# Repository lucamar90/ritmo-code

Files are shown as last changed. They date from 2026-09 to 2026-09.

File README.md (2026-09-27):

<div align="center">

Clawd

# Ritmo Code

**I limiti d'uso di Claude Code, in tempo reale su uno schermo touch da 3,5".**<br>
Senza computer acceso, senza app, senza cloud.

**Italiano** · [English](README.en.md)






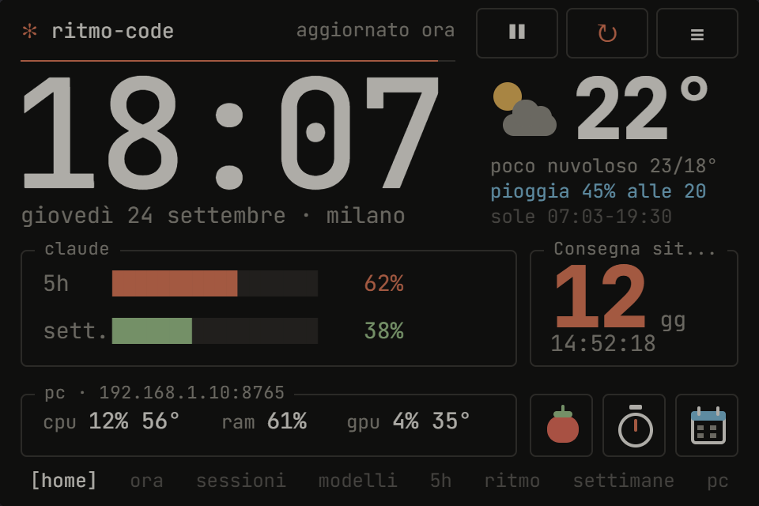
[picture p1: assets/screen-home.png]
Ritmo Code: home con ora, meteo, riepilogo Claude e PC


</div>

Ritmo Code è un piccolo schermo da scrivania che mostra quanto hai consumato delle finestre
di **5 ore** e **settimanale** del tuo abbonamento Claude, quando si azzerano, se il ritmo della
settimana è sostenibile e se i modelli rispondono. Il dispositivo interroga direttamente la API
di Anthropic via Wi-Fi e legge i dati dagli header della risposta.

Sulla stessa scrivania fa anche da cruscotto: ora e meteo, e con l'app
[**Ritmo Code PC Monitor**](#ritmo-code-pc-monitor) le statistiche complete del tuo PC.

L'interfaccia è in stile terminale di Claude Code, in **italiano** o inglese, con navigazione
100% touch (scorri ← → tra le pagine, nessun tasto fisico).

---

## Schermate

| | |
|---|---|
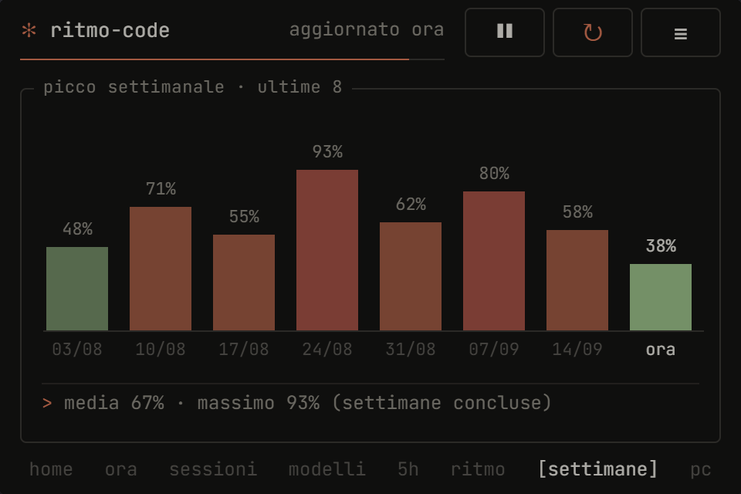
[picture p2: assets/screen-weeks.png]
Settimane
| Home **Home** — ora, data, meteo (Open-Meteo), riepilogo di 5h e settimana, stato dei modelli e riga del PC collegato. Ci torna da sola dopo qualche minuto senza tocchi. |  **Settimane** — picco raggiunto in ciascuna delle ultime 8 settimane, con media e massimo. |
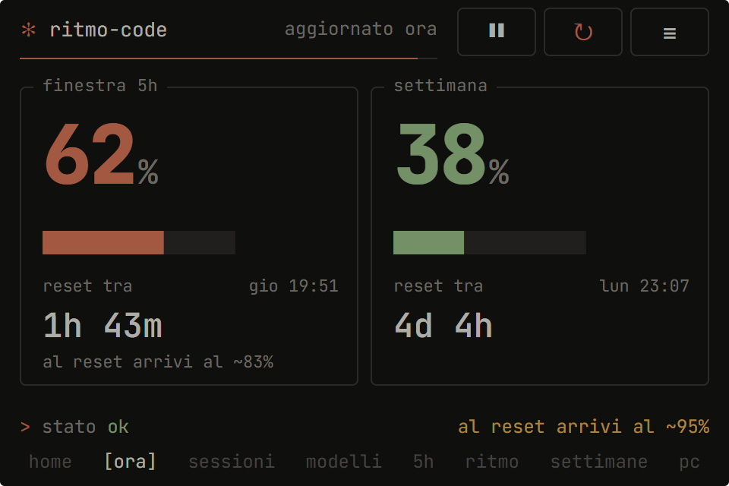
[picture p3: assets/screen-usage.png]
Ora
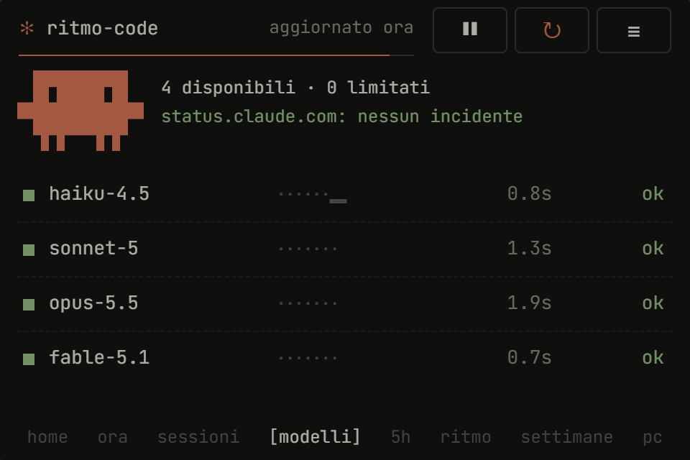
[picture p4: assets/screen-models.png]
Modelli
|  **Ora** — percentuale e barra a blocchi di 5h e settimana, conto alla rovescia e orario del reset, stato complessivo e **ritmo settimanale** (con la tacca "dove dovresti essere"). Sotto il conto alla rovescia della 5h, la **previsione**: "a questo ritmo: fine 16:40" oppure "al reset arrivi al ~70%". |  **Modelli** — Clawd reagisce allo stato; per Haiku, Sonnet, Opus e Fable una sonda reale con esito e latenza, più gli incidenti da status.claude.com. |
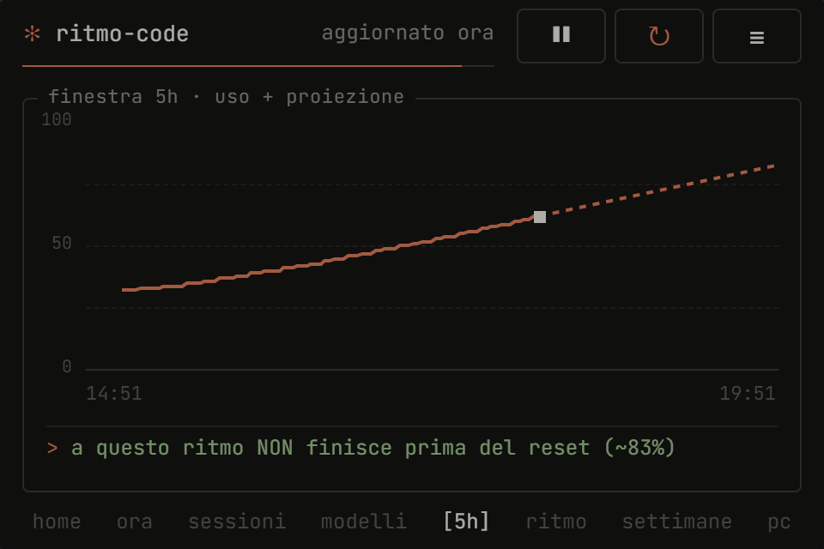
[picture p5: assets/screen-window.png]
Finestra 5h
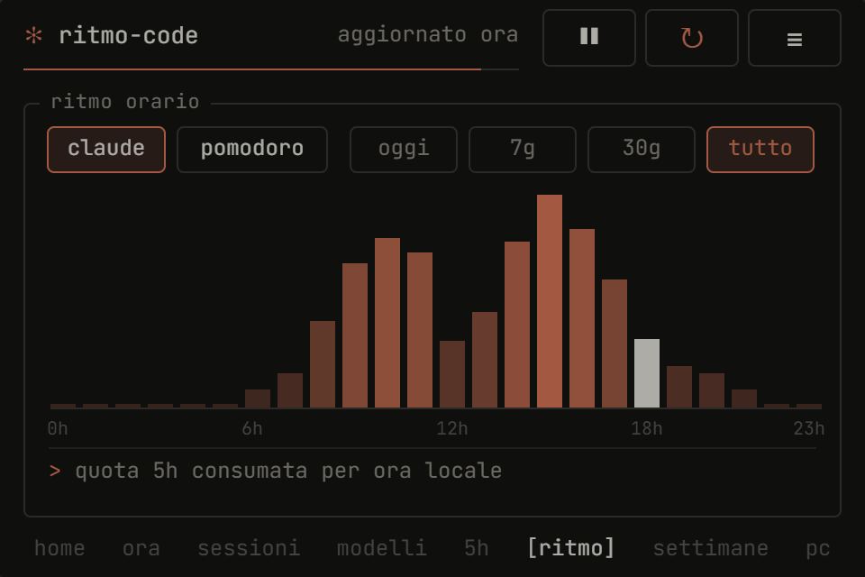
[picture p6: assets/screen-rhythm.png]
Ritmo
|  **Finestra 5h** — uso della finestra corrente e proiezione tratteggiata: ti dice se, a questo ritmo, finisci la quota prima del reset. |  **Ritmo** — quota consumata per ora del giorno, con filtro **oggi · 7g · 30g · tutto** (storico per giorno salvato sul dispositivo). La riga in basso alterna i **progetti** del periodo: toccala per il pannello completo. |
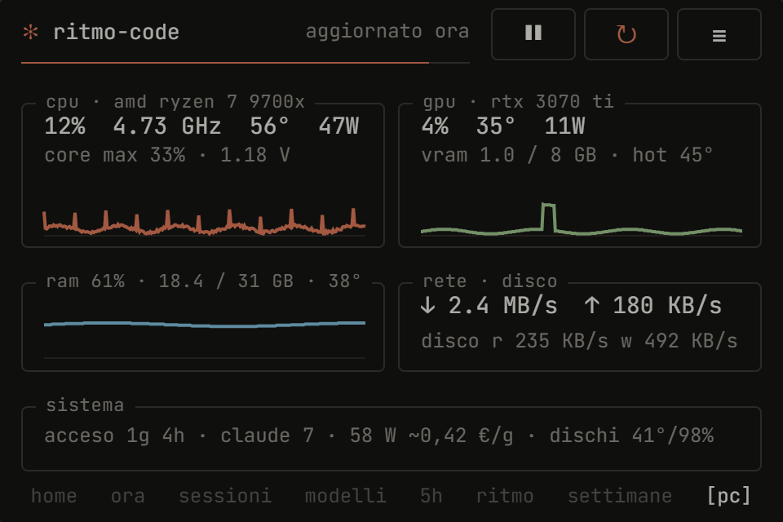
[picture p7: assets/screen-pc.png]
PC
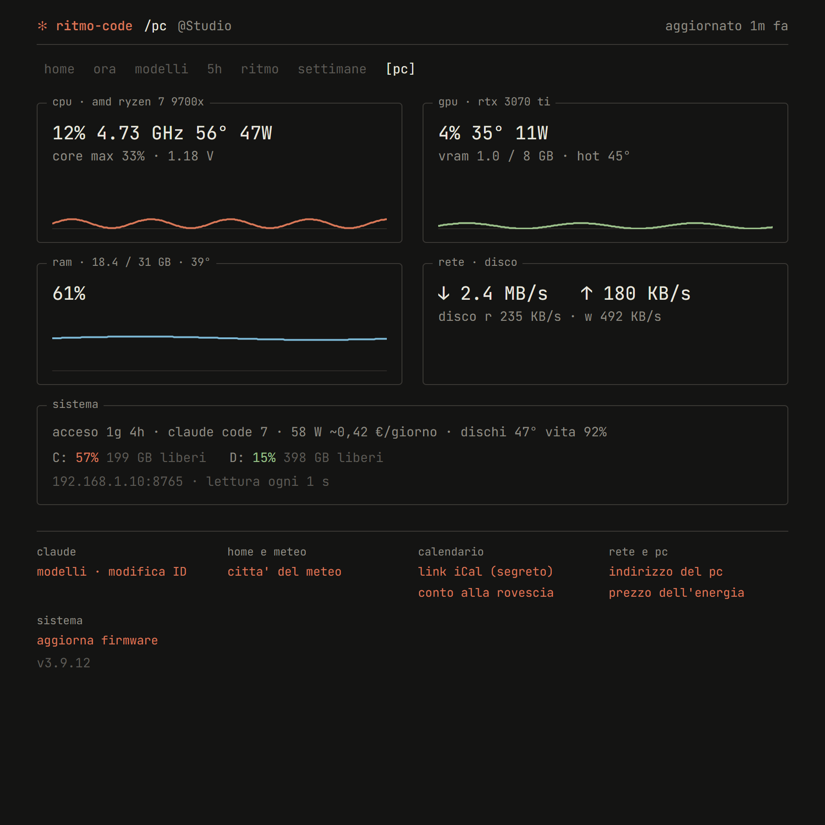
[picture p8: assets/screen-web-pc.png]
Pannello web, pagina pc
|  **PC** — CPU (carico, GHz, temperatura, watt, core più carico), GPU (VRAM e hot spot), RAM con temperatura dei moduli, rete, disco, grafici che avanzano a ogni lettura (4 minuti a 1 s), uptime, sessioni di Claude Code, consumo e costo al giorno, temperatura e vita residua dei dischi. |  **Pannello web · pc** — le stesse pagine del dispositivo nel browser, con i dischi uno per uno. |
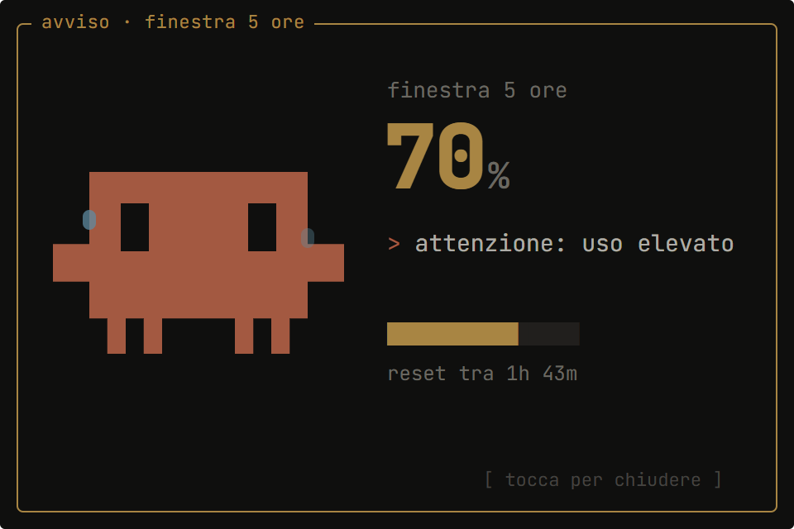
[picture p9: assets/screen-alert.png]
Avviso di soglia
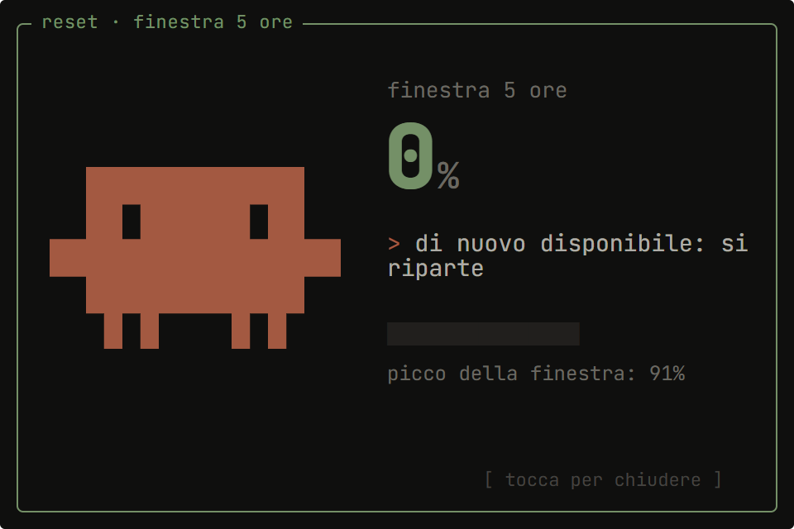
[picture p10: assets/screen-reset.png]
Avviso di reset
|  **Avvisi di soglia** — a 25, 50, 70 e 100% un'animazione a schermo intero con Clawd che reagisce al livello. |  **Avviso di reset** — quando una finestra che aveva superato l'80% torna disponibile. |
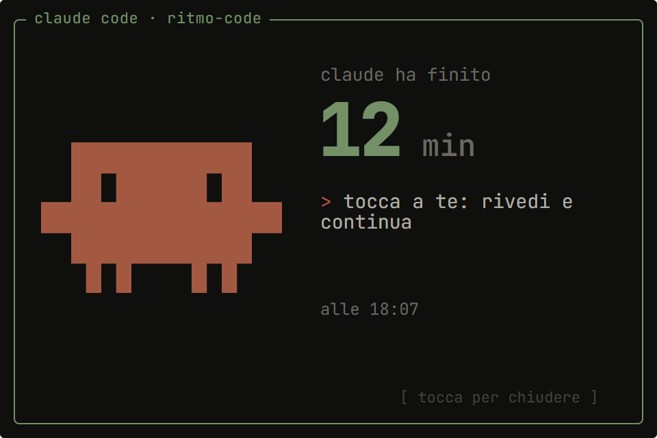
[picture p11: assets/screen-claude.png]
Claude ha finito
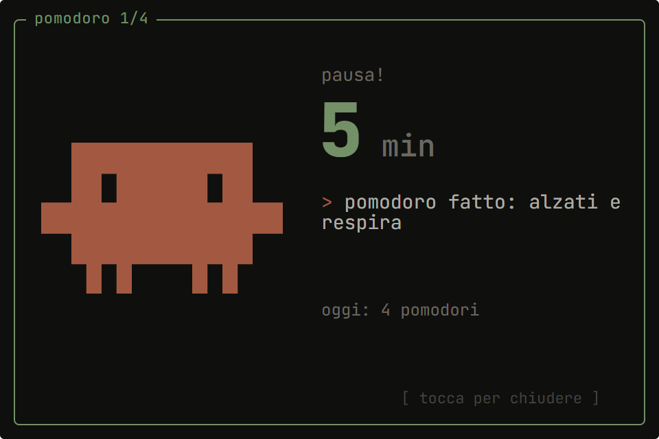
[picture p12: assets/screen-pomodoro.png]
Pomodoro
|  **Claude Code** — con gli hook installati dal PC Monitor, Clawd ti avvisa quando Claude ha finito (e dopo quanto) o aspetta un permesso. Resta finché non lo tocchi o riscrivi a Claude. |  **Timer e pomodoro** — tocca l'ora o il pomodoro nella home: pomodoro 25/5, 50/10 o 15/3, oppure timer da 5 a 30 minuti. Conto alla rovescia sotto l'ora, avviso a fine fase, pomodori di oggi. |
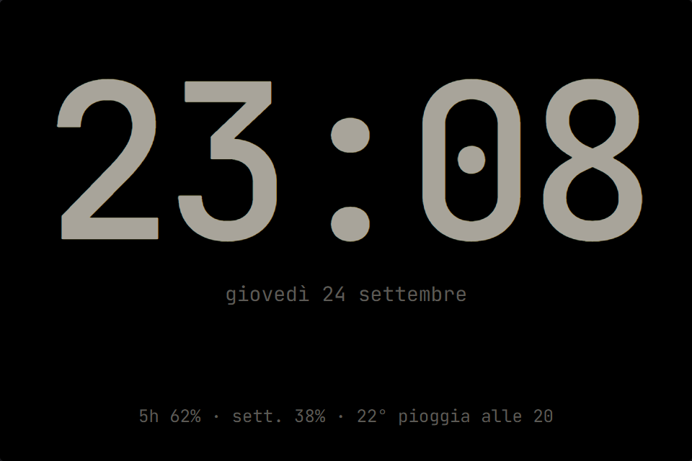
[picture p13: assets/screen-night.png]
Orologio notturno
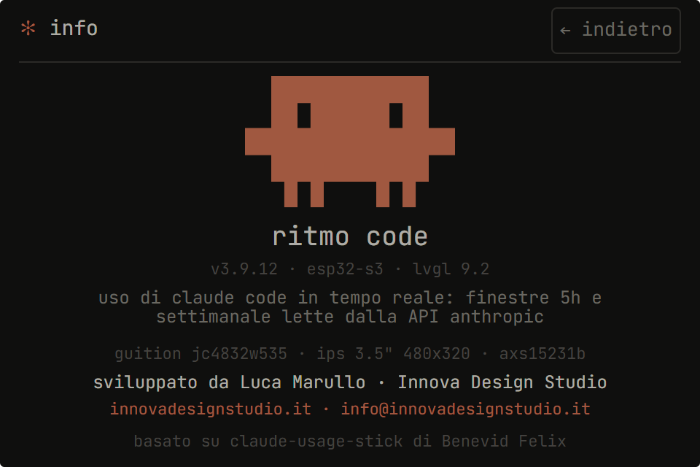
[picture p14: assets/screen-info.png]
Info
|  **Orologio notturno** — di notte, dopo 30 secondi senza tocchi, l'ora a tutto schermo in grigio caldo con data, uso di 5h e settimana e pioggia in arrivo. Luminosità tenue o molto tenue; in alternativa lo schermo si spegne. |  **Info** — versione del firmware, hardware e crediti. |
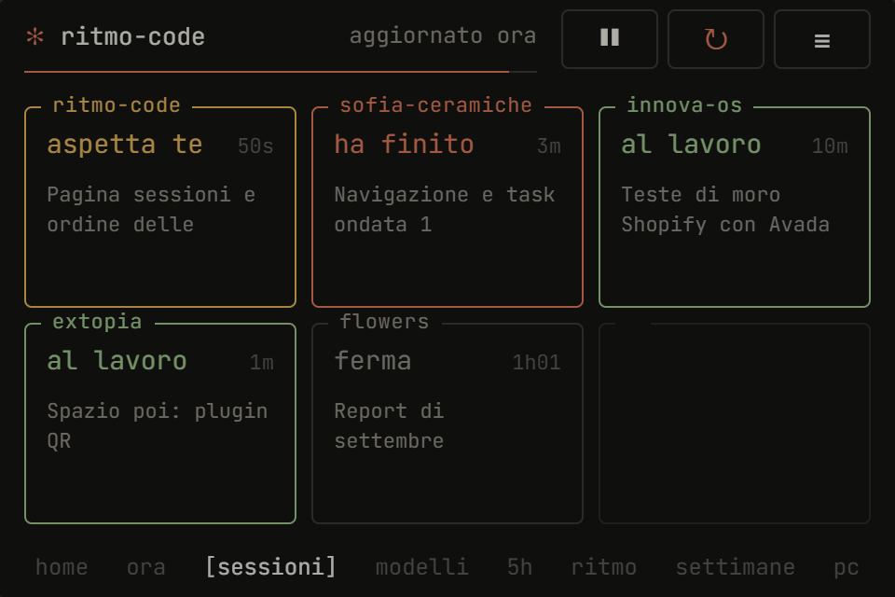
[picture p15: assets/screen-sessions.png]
Sessioni
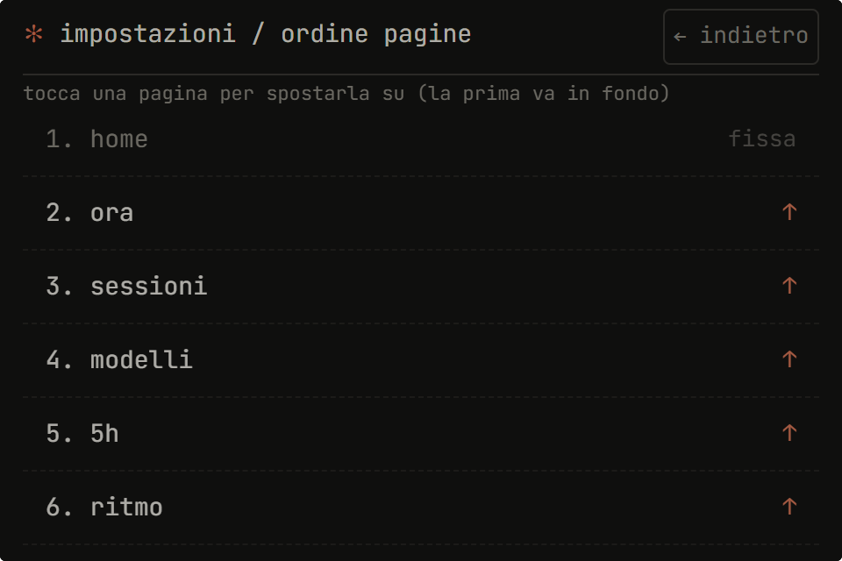
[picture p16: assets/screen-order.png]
Ordine delle pagine
|  **Sessioni** — le sessioni di Claude Code aperte sul PC (fino a 6): progetto, stato col suo colore (**aspetta te**, **ha finito**, **al lavoro**, **ferma**), da quanto e titolo della scheda. Un tocco porta la sessione in primo piano sul PC; se sei su questa pagina, chi finisce o ti aspetta lampeggia invece di aprire l'avviso a schermo intero. |  **Ordine delle pagine** — in *Impostazioni → schermo → ordine pagine* scegli la sequenza delle pagine (la home resta la prima). Predefinito: home · ora · sessioni · modelli · 5h · ritmo · settimane · pc. |
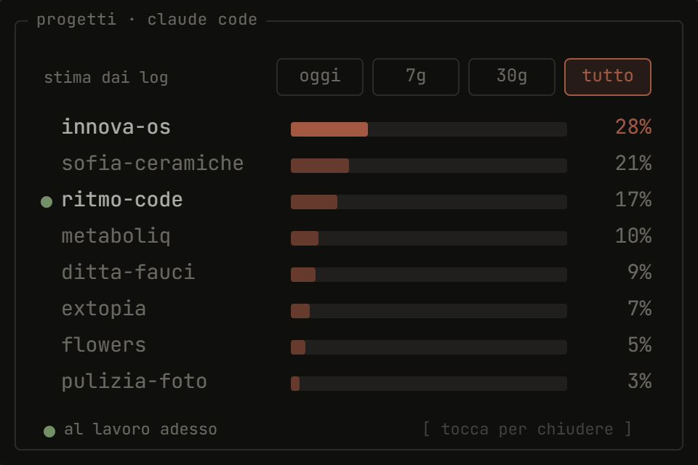
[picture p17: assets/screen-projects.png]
Progetti
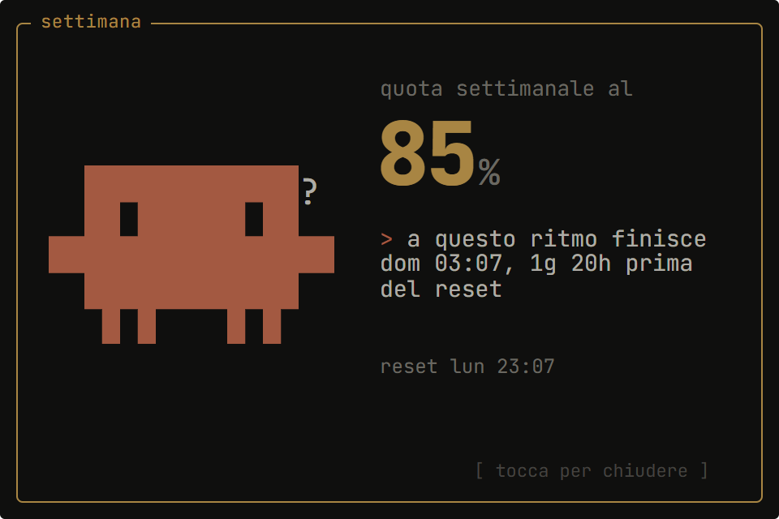
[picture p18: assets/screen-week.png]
Avviso settimana
|  **Progetti** — quanto pesa ogni progetto su Claude Code nel periodo scelto (fino a 8), con barra e percentuale; il pallino verde segna quelli con una sessione al lavoro adesso. Dati dal PC Monitor 1.9. |  **Avviso settimana** — se la settimana supera il 70, 85 o 95% e a questo ritmo finirebbe almeno 12 ore prima del reset, Clawd ti avvisa (una volta a settimana). |
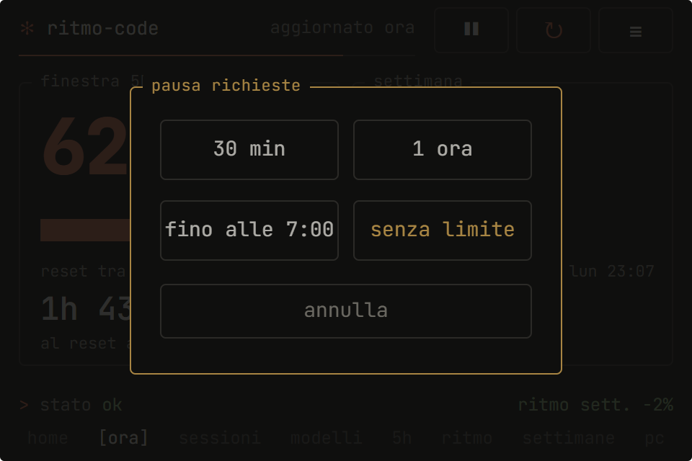
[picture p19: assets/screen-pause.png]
Pausa a tempo
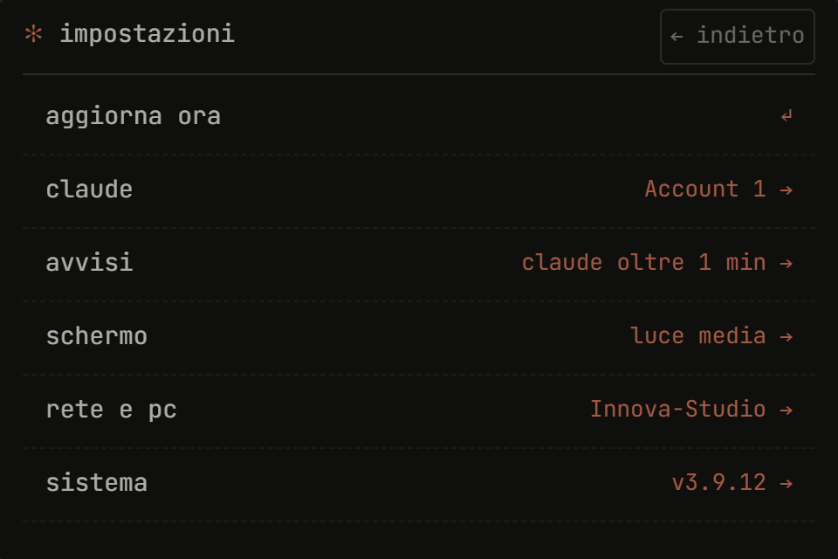
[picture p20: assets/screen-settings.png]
Impostazioni
|  **Pausa richieste** — il tasto ❚❚ in testata ferma le richieste; tenuto premuto offre 30 min, 1 ora, fino alle 7:00 o senza limite. |  **Impostazioni** — in cinque gruppi: **claude** (intervallo, account, modelli, token), **avvisi** (Claude Code, calendario, suoni sul pc, settimana, reset, pausa), **schermo** (luminosità e luminosità automatica, notte e orologio notturno, attenuazione, home, slideshow, tendina, ordine delle pagine), **rete e pc** (Wi-Fi, indirizzo, intervallo pc, ricerca della scheda per le sessioni) e **sistema** (lingua, fuso, aggiornamento firmware, spazio libero e RAM, info; *cancella tutto* chiede due tocchi e il PIN). |

> Doppio tocco su **✻ ritmo-code** in alto: riapre l'ultimo avviso (Claude, timer, pomodoro o soglia).

Le immagini arrivano dal [simulatore](#simulatore) e si rigenerano con `node tools/capture_screens.js`.

### Pannello web

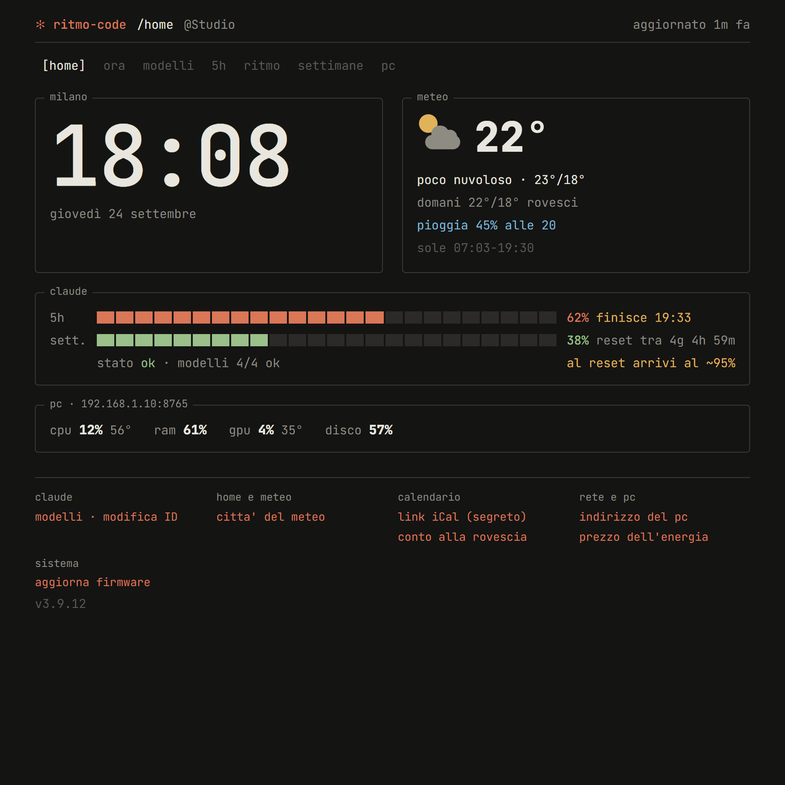
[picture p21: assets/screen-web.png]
Pannello web di Ritmo Code


Da qualsiasi browser sulla stessa rete apri **`http://<ip-del-dispositivo>/`**: l'IP è in
*Impostazioni → rete locale* (su Mac e iPhone funziona anche `http://ritmo-code.local/`).

- Meteo e PC collegato in un riquadro in alto.
- Finestra 5h e settimana con conto alla rovescia, stato, ritmo e previsione (della 5h e della settimana).
- Le schede del dispositivo: **home · ora · modelli · 5h · ritmo · settimane · pc** (la pagina sessioni c'è solo sul dispositivo).
- **Andamento** dello storico con filtro **6h · 24h · tutto**.
- **Ritmo orario** con filtro **oggi · 7g · 30g · tutto** e, sotto, i **progetti** del periodo con il pallino di quelli al lavoro.
- Modelli sondati: ID, esito, latenza, ultimo controllo.
- **Picco settimanale** delle ultime 8 settimane.
- Collegamenti per **modificare gli ID dei modelli**, impostare **città, PC e prezzo dell'energia** (`/home`) e **aggiornare il firmware**.

Si aggiorna da solo ogni 30 secondi leggendo solo la memoria del dispositivo (`/api/status`):
nessuna richiesta in più ad Anthropic, e il token non viene mai esposto.

<br clear="right">

---

## Funzioni

- **Finestre 5h e settimanale** con reset, proiezione ed esito complessivo (`ok` · `attenzione` · `bloccato`).
- **Ritmo settimanale**: percentuale usata meno percentuale di settimana trascorsa. Verde se sei sotto ritmo, ambra fino a +15%, rosso oltre. Alternato alla **previsione**: "al reset arrivi al ~70%" oppure "a questo ritmo finisce gio 14:00".
- **Previsione della 5h** col ritmo degli ultimi 45 minuti, nella pagina ora ("a questo ritmo: fine 16:40") e in home, dove "finisce 16:40" prende il posto dell'orario di reset quando la quota finisce prima.
- **Avviso settimana**: sopra il 70, 85 o 95% (*Impostazioni → avvisi → avviso settimana*, predefinito 85%), se a questo ritmo la quota settimanale finisce almeno 12 ore prima del reset, un avviso a schermo intero dice quando finisce e con quanto anticipo. Una volta a settimana.
- **Progetti di Claude Code**: il PC Monitor legge i log delle sessioni (`~/.claude/projects`) e stima quanto pesa ogni progetto oggi, in 7 giorni, in 30 giorni e da sempre (token pesati come i prezzi e per famiglia del modello). Il progetto è il repository git della cartella di lavoro, con il nome del remote; nelle cartelle `clienti\` e `interno\` conta la sottocartella. Nella pagina ritmo e nel pannello web.
- **Storico settimanale**: picco di ogni settimana, salvato sul dispositivo per account.
- **Avvisi** di soglia (25/50/70/100%) e di **reset** (disattivabile).
- **Timer e pomodoro**: tocca l'ora o la riga con il pomodoro nella home. Tre impostazioni pronte, **25/5**, **50/10** e **15/3** (focus/pausa in minuti, pausa lunga dopo il quarto), oppure timer da 5, 10, 15 o 30 minuti. Il conto alla rovescia scorre sotto l'ora e nella testata, a fine fase Clawd lo annuncia a schermo intero (anche di notte) e i pomodori di oggi restano contati. Si comanda anche dal PC (menu dell'icona) e, con *Impostazioni → avvisi → claude durante il focus → alla pausa*, gli avvisi di Claude aspettano la fine del focus.
- **Calendario**: incolla il link segreto iCal di Google Calendar (o Outlook) nel pannello web, pagina `/home`. Il PC Monitor scarica gli eventi ogni 5 minuti (anche quelli ricorrenti); sotto l'ora compare "tra 12 min: call cliente" o "in corso: … fino 16:00", e 5, 10 o 15 minuti prima arriva un avviso a schermo intero con suono sul PC (*Impostazioni → avvisi → avviso calendario*). Il link lo legge solo il PC collegato.
- **Sessioni di Claude Code**: una pagina con le sessioni aperte sul PC e il loro stato. Un tocco apre la sessione: il PC Monitor risale dal processo di Claude alla finestra del terminale e la porta davanti; in **Warp** scorre anche le schede (Ctrl+PgGiù) finché il titolo corrisponde (*Impostazioni → rete e pc → sessioni: cerca la scheda*). Sotto il riquadro compare l'esito: *aperta*, *cambia scheda* o *finestra non trovata*.
- **Avvisi di Claude Code**: Clawd ti dice quando Claude ha finito un lavoro (con la durata) o aspetta un permesso, tramite gli hook e l'app [PC Monitor](#ritmo-code-pc-monitor). Mentre Claude lavora la ✻ in testata gira come in Claude Code e il riquadro della home dice quante sessioni sono **al lavoro**.
- **Modelli**: una sonda per ciclo a rotazione. Gli **ID sono modificabili** dal dispositivo o dal browser: se Anthropic rinomina un modello non serve ricompilare.
- **Modalità notte** in una fascia oraria (22, 23 o 00 → 07): **orologio a tutto schermo** con luminosità tenue o molto tenue, oppure schermo spento, e di predefinito **aggiornamenti in pausa**. Il primo tocco riaccende soltanto, senza premere nulla. **Attenuazione** dopo 1, 5 o 10 minuti senza tocchi.
- **Luminosità automatica**: piena di giorno e bassa la sera, dal tramonto all'alba (orari presi dal meteo) oppure 20→07 o 21→07. Un tocco sul livello vale fino al passaggio successivo.
- **Pausa richieste** dal tasto in testata, senza limite o a tempo; riparte da sola.
- **Tendina** (trascina giù dalla testata): segnale Wi-Fi, indirizzo e PC collegato (tocca per la pagina rete), **quattro tasti a scelta** fra richieste, timer, luce, suoni sul PC, aggiorna, calendario e meteo (*Impostazioni → schermo → tendina*), il **riepilogo di oggi** (pomodori, richieste a Claude e tempo di lavoro, 5 ore), il **prossimo evento** (tocca per aprire il calendario su quel giorno) e gli ultimi tre avvisi.
- **Promemoria pausa**: dopo 45, 60 o 90 minuti di PC in uso senza staccare (mouse e tastiera, letti dal PC Monitor) Clawd ti ricorda di alzarti; si ripete ogni mezz'ora e si azzera dopo 5 minuti lontano dal PC (*Impostazioni → avvisi*).
- **Media**: quando sul PC parte la musica o un video (Spotify, browser, lettori) si apre la pagina media: copertina, titolo, artista, barra di avanzamento (tocca per spostarti), indietro / play-pausa / avanti e volume del PC. Si apre anche dalla tendina; l'apertura automatica si spegne in *Impostazioni → schermo*. Serve il PC Monitor 1.8.
- **Conto alla rovescia**: fino a tre date con nome ("consegna sito tra 12 giorni"), da creare sul dispositivo (tendina → conto) o dal pannello web, pagina `/home`. All'arrivo Clawd avvisa con un suono sul PC.
- **Claude oggi**: richieste finite, tempo totale di lavoro e la più lunga, nella tendina e nella pagina ritmo (scheda claude, periodo *oggi*).
- **Home e meteo**: ora, data e previsioni per la città scelta (Open-Meteo, gratuito e senza chiave), aggiornate ogni 30 minuti. Tocca il meteo per le **previsioni dei 7 giorni**.
- **Statistiche del PC** tramite l'app [Ritmo Code PC Monitor](#ritmo-code-pc-monitor), lette ogni 1, 3, 5 secondi o 1 minuto.
- **Fino a 4 account**, cifrati con lo stesso PIN: viene interrogato solo quello attivo.
- **Reti Wi-Fi salvate**: fino a 3, con rete preferita e "dimentica"; il segnale in dBm è nelle impostazioni.
- **Aggiornamento firmware con un tocco**: il dispositivo controlla da solo l'ultima release su GitHub (dopo l'avvio e una volta al giorno), la testata mostra *nuova v…* e in *Impostazioni → sistema → aggiornamenti* si installa con un tocco. Resta anche l'aggiornamento dal browser, protetto da un codice mostrato sullo schermo; in entrambi i casi c'è il **ritorno automatico** alla versione precedente se il nuovo firmware non parte.
- **Layout in sezione aurea**: margini, colonne, altezze dei riquadri e spazi seguono φ e la scala di Fibonacci (5 · 8 · 13 · 21 · 34 · 55 · 89), con padding simmetrici in ogni pagina.
- **Intervallo** di aggiornamento da 30 s a 30 min, **slideshow** automatico, **luminosità**, **fuso orario** (Roma con ora legale automatica, o GMT±N).

---

## Ritmo Code PC Monitor

Pagina pc

App per Windows nella cartella [`ritmo-code-pc-monitor/`](ritmo-code-pc-monitor/) che invia al
dispositivo le statistiche del computer: CPU, GPU, RAM, rete, dischi, uptime, sessioni di Claude
Code aperte e, tramite [LibreHardwareMonitor](https://github.com/LibreHardwareMonitor/LibreHardwareMonitor)
incluso nel pacchetto, temperature, consumi, ventole e salute dei dischi. Dalla 1.9 legge anche i
log di Claude Code sul PC per la ripartizione per **progetto** (al dispositivo arrivano solo nomi e
percentuali).

I dati restano sulla rete di casa: il dispositivo legge `http://<ip-del-pc>:8765/data.json`, che
non contiene nomi di file, processi o finestre. I sensori disponibili dipendono dall'hardware:
temperature, consumi e dischi compaiono solo se LibreHardwareMonitor riesce a leggerli su quel PC.

<br clear="right">

### Installazione su Windows

**Serve:** Windows 10 o 11, un account amministratore, il PC e il dispositivo sulla **stessa rete**
(il dispositivo usa solo il Wi-Fi a **2,4 GHz**; il PC può stare anche via cavo o sul 5 GHz dello
stesso router). Per creare il pacchetto serve anche [Python 3.8+](https://www.python.org/downloads/).

**1. Prendi il pacchetto**

Il modo più rapido: scarica **`RitmoCodePcMonitor-…-windows.zip`** dall'[ultima release](https://github.com/lucamar90/ritmo-code/releases/latest)
e scompattalo; contiene già tutto, non serve Python. Per crearlo da sorgente invece (su qualsiasi PC Windows):

```bat
cd ritmo-code-pc-monitor
pip install pyinstaller
build_exe.bat
```

`build_exe.bat` crea due eseguibili e, se manca, scarica LibreHardwareMonitor 0.9.6. Alla fine la
cartella `dist\` contiene tutto quello che serve:

```
dist\
  RitmoCodePcMonitor-nascosto.exe   senza finestra, avviato con Windows (icona vicino all'orologio)
  RitmoCodePcMonitor.exe            con finestra, per le verifiche
  LibreHardwareMonitor\             sensori, web server solo su 127.0.0.1:8085
  installa.bat · disinstalla.bat · LEGGIMI.txt
```

**2. Installa** sul PC da monitorare

1. Copia la cartella (`dist\` o quella scompattata dallo zip) in un posto fisso, per esempio `C:\RitmoCodePcMonitor` (gli avvii automatici
   puntano lì: non spostarla dopo).
2. Doppio clic su **`installa.bat`** e conferma i permessi di amministratore. Lo script:
   - crea la regola del firewall **"Ritmo Code PC Monitor"**: porta TCP 8765 aperta **solo alla rete locale**;
   - registra LibreHardwareMonitor come attività all'accesso con privilegi elevati (servono per le temperature);
   - mette l'app in *Esecuzione automatica* e la avvia;
   - apre la pagina di collegamento.
3. Se Windows SmartScreen avvisa che l'app non è riconosciuta (gli eseguibili non sono firmati),
   scegli **Ulteriori informazioni → Esegui comunque**.

**3. Collega il PC al dispositivo**

1. Il dispositivo deve essere acceso, sbloccato con il PIN e sulla stessa rete.
2. La pagina **`http://127.0.0.1:8765/`** (si apre da sola, oppure doppio clic sull'icona) cerca il
   dispositivo sulla rete locale. Se non lo trova, controlla la rete e premi **Cerca di nuovo**;
   in alternativa imposta l'indirizzo del PC dal pannello web del dispositivo (vedi sotto).
3. Inserisci il **PIN** del dispositivo e premi **Collega questo PC**. L'app comunica al dispositivo
   il suo indirizzo; il PIN serve solo per questa operazione e non viene salvato.
4. Dopo pochi secondi la pagina **pc** del dispositivo si riempie. La frequenza di lettura si sceglie
   sul dispositivo in *Impostazioni → intervallo pc* (1 s, 3 s, 5 s, 1 min).

In alternativa l'indirizzo del PC (`192.168.x.x:8765`) si imposta anche dal pannello web del
dispositivo, pagina `/home`.

**4. Icona nell'area di notifica**

L'app resta vicino all'orologio di Windows con l'icona di Clawd:

- **passandoci sopra** mostra CPU, GPU, RAM e se il dispositivo sta leggendo i dati;
- **doppio clic** apre la pagina di stato e collegamento;
- **clic destro** apre il pannello del dispositivo o chiude l'app (**Esci**);
- **clic destro → Timer e pomodoro** avvia sul dispositivo un pomodoro (25/5, 50/10, 15/3) o un timer, lo ferma o salta la fase; in cima mostra il timer in corso.

**5. Avvisi di Claude Code**

Avviso: Claude ha finito

Il dispositivo può avvisarti quando Claude Code **ha finito** un lavoro o **aspetta un tuo permesso**,
anche se stai guardando un'altra finestra o ti sei alzato dalla scrivania.

1. Nella pagina **`http://127.0.0.1:8765/`**, riquadro *avvisi di claude code*, premi **Attiva gli avvisi**.
   L'app aggiunge cinque [hook](https://docs.claude.com/en/docs/claude-code/hooks) a
   `~/.claude/settings.json` (`UserPromptSubmit`, `Stop`, `Notification` e, dalla 1.9, `SessionStart` e
   `SessionEnd` per la pagina sessioni) senza toccare il resto del file; la prima volta ne salva una
   copia in `settings.json.ritmo-bak`. Se c'erano già gli hook della 1.8, la 1.9 aggiunge da sola i due nuovi.
2. Apri una nuova sessione di Claude Code: gli hook valgono per le sessioni avviate dopo.

Gli hook chiamano solo `http://127.0.0.1:8765` e l'app inoltra l'avviso al dispositivo, che lo accetta
solo dal PC collegato. Arrivano il nome della cartella del progetto e, per la pagina sessioni, il
**titolo** della sessione (il riassunto di poche parole che Claude Code dà alla scheda); nient'altro del
contenuto della sessione.
A schermo l'avviso si chiude da solo dopo 5, 10 o 30 secondi (*Impostazioni → chiudi avviso claude*, 30 s
predefinito) oppure resta finché non lo tocchi o scrivi di nuovo a Claude (*mai*); di
notte, con lo schermo spento o l'orologio notturno, non compare. In *Impostazioni → avvisi claude code*
scegli quando mostrarlo: **sempre**, solo per lavori **oltre 1 min** (predefinito) o **oltre 5 min**,
oppure **spento**. Le richieste di permesso compaiono sempre, tranne con *spento*.

Per toglierli: **Disattiva** nella stessa pagina.

**6. Suoni e notifiche sul PC**

Quando il dispositivo mostra un avviso (fine del timer, pausa e ripresa del pomodoro, Claude ha finito o
aspetta, soglie di utilizzo e reset) lo manda anche al PC collegato, che suona (un suono diverso per ogni
tipo) e mostra una notifica di Windows. Nella pagina `http://127.0.0.1:8765/`, riquadro *suoni e
notifiche*, scegli suono e notifica e il tipo di suono: **suoni di Windows** (predefiniti, seguono il volume
dei *Suoni di sistema* e si sentono anche in desktop remoto) o **melodie Ritmo Code** (con volume proprio);
**Prova** fa sentire com'è. Sul dispositivo si accende e
spegne da *Impostazioni → suoni sul pc*; di notte resta muto. Il PC accetta gli avvisi solo dal
dispositivo collegato.

<br clear="right">

**Problemi comuni**

| Sintomo | Cosa fare |
|---|---|
| Sul dispositivo: *pc spento o Ritmo Code PC Monitor non attivo* | Controlla che l'icona sia vicino all'orologio. Apri `http://<ip-del-pc>:8765/data.json` da un altro dispositivo: se non risponde, la regola del firewall manca (rilancia `installa.bat`) o il router isola i client Wi-Fi. |
| Il dispositivo non trova il PC dopo un riavvio del router | L'IP del PC è cambiato: rifai **Collega questo PC**, oppure riserva l'indirizzo del PC nel router (DHCP statico). |
| Il PC non trova il dispositivo | Il dispositivo è su un'altra rete (per esempio l'ospite o un altro SSID): in *Impostazioni → reti wifi* dimentica quella sbagliata. |
| Temperature, watt o dischi vuoti | LibreHardwareMonitor deve girare come amministratore: esci e rientra in Windows, o rilancia `installa.bat`. Alcuni chip della scheda madre non sono supportati. |
| *Porta 8765 già in uso* | Sono aperte insieme la versione con finestra e quella nascosta: chiudine una (icona → **Esci**). |
| Avevi già LibreHardwareMonitor per un'altra app | `installa.bat` lo ferma e usa il suo (ne basta uno); `disinstalla.bat` lo riattiva. |

**Aggiornare o disinstallare**

- Per aggiornare: icona → **Esci**, sostituisci i file nella cartella con quelli del nuovo `dist\`
  e rilancia `installa.bat`.
- Per rimuovere tutto: **`disinstalla.bat`** toglie avvio automatico, attività e regola del firewall;
  poi la cartella si può cancellare.

Da sorgente l'app si avvia anche con `python ritmo_pc_monitor.py` (`--print` per una lettura di
prova, `--port`, `--interval`, `--no-lhm`, `--no-tray`). Dettagli sui dati inviati nel
[README dell'app](ritmo-code-pc-monitor/README.md).

---

## Hardware

| | |
|---|---|
| Scheda | **Guition JC4832W535**, ESP32-S3 con schermo IPS touch capacitivo da 3,5" · 480×320 · **8 MB PSRAM** · **16 MB flash** |
| Chip | ESP32-S3 (USB nativa) |
| Display | **AXS15231B**, interfaccia QSPI |
| Touch | **AXS15231B** capacitivo, I²C `0x3B` |

> **La PSRAM OPI è obbligatoria**: i buffer grafici non entrano nella RAM interna.

Pin e configurazione validata di display, colori e touch sono in
[`firmware/RIFERIMENTO-HARDWARE-LVGL.md`](firmware/RIFERIMENTO-HARDWARE-LVGL.md); lo sketch di
bring-up di riferimento è in [`firmware/bringup/`](firmware/bringup/).

**Case stampabile in 3D:** [`3D Case/`](3D%20Case/) contiene un case semplice
(`Case_JC3248W535C.stl`) e una versione articolata con supporto per il display (`Articolato/`).

---

## Come funziona

Il dispositivo invia una richiesta **minima** (`max_tokens: 1`) a
`https://api.anthropic.com/v1/messages`, **ignora il corpo** della risposta e legge l'uso dagli header:

```
anthropic-ratelimit-unified-status                allowed | allowed_warning | rejected
anthropic-ratelimit-unified-5h-utilization        0–1   (finestra 5 ore)
anthropic-ratelimit-unified-5h-reset              epoch
anthropic-ratelimit-unified-7d-utilization        0–1   (finestra settimanale)
anthropic-ratelimit-unified-7d-reset              epoch
anthropic-ratelimit-unified-representative-claim  five_hour | seven_day
anthropic-ratelimit-unified-fallback-percentage
anthropic-ratelimit-unified-overage-status / -overage-disabled-reason
```

Lo stato dei modelli combina gli incidenti di `status.claude.com` con una **sonda per modello**:
a ogni ciclo il dispositivo prova il modello successivo della rotazione e registra codice HTTP e
latenza. La sonda resta una richiesta separata, così l'aggiornamento dell'uso non costa di più.

Ogni richiesta è una vera chiamata API, anche se minima: con un account aziendale è visibile agli
amministratori come qualsiasi uso di Claude Code. Per ridurle usa un intervallo più lungo e la
pausa notturna.

### Il token (`claude setup-token`)

In un terminale, con **Claude Code** installato e collegato al tuo abbonamento (**Pro** o **Max**):

```bash
claude setup-token
```

Si apre un login **OAuth** nel browser e ricevi un **token a lunga durata** `sk-ant-oat01-…`.
È un token di **Claude Code**: una chiamata "normale" alla Messages API con questo token viene di
solito rifiutata, e senza il prompt di sistema di Claude Code i modelli oltre Haiku rispondono 429.
Il dispositivo invia il prompt di sistema e gli stessi header di Claude Code
(`anthropic-beta: oauth-2025-04-20` e il suo `User-Agent`), così la API risponde con gli header dei
limiti. Il token si inserisce **una volta** dal browser e resta **cifrato** sul dispositivo.

### ⚠️ Leggi prima di usare un token di abbonamento

**Anthropic non consente l'uso dei token OAuth degli abbonamenti in strumenti di terze parti.**
Con una policy formalizzata il **4 aprile 2026**, Anthropic ha chiarito che l'OAuth di
Free/Pro/Max (la credenziale prodotta da `claude setup-token`) è destinato **solo** a Claude Code e
claude.ai, e che usarlo in altri prodotti viola i Consumer Terms. Ritmo Code è uno strumento di
terze parti e il metodo descritto sopra, che si presenta come il client Claude Code, è proprio lo
schema a cui si riferisce quella policy.

- **Oggi funziona**, ma *funzionare* non significa *essere permesso*.
- Il rischio è sul **tuo account**: sono stati segnalati errori di autenticazione e blocchi.
- Anthropic può cambiare la API o bloccare questo schema in qualsiasi momento.

Questo progetto non è affiliato ad Anthropic. **Se non accetti questo rischio sul tuo account, non
usare un token di abbonamento con questo firmware.**

Fonti: [The Register](https://www.theregister.com/2026/02/20/anthropic_clarifies_ban_third_party_claude_access/) ·
[WinBuzzer](https://winbuzzer.com/2026/02/19/anthropic-bans-claude-subscription-oauth-in-third-party-apps-xcxwbn/)

---

## Compilare e caricare

Prerequisiti (versioni provate):

- `arduino-cli` 1.4.x · core `esp32:esp32` **3.3.11**
- librerie: **GFX Library for Arduino** 1.6.5 · **lvgl** 9.2.2
- su Windows: **Git Bash** per gli script `.sh`

```bash
cd firmware/ritmo_code
./build.sh                    # compila (ottimizzato -O2) ed esporta il .bin
./build.sh upload COM3        # compila e carica via USB (macOS: /dev/cu.usbmodemXXXX)
./build.sh monitor COM3       # log seriale a 115200
./build.sh ota <ip> <codice>  # compila e carica via Wi-Fi
```

FQBN: `esp32:esp32:esp32s3:PSRAM=opi,FlashSize=16M,PartitionScheme=custom,CDCOnBoot=cdc,USBMode=hwcdc,FlashMode=qio`

### Aggiornamento via Wi-Fi

Sul dispositivo apri **Impostazioni → aggiorna firmware**: compaiono l'indirizzo e un **codice di
6 cifre** valido 5 minuti (5 tentativi sbagliati chiudono la sessione). Poi, dallo stesso Wi-Fi:

- `./build.sh ota <ip> <codice>`, oppure
- apri `http://<ip>/update`, scegli `build/esp32.esp32.esp32s3/ritmo_code.ino.bin` e inserisci il codice.

Token, PIN, account, storico e impostazioni restano intatti. Il cavo USB funziona sempre come
alternativa.

### Note di build

`build.sh` passa `-DLV_CONF_INCLUDE_SIMPLE -I<sketch>` così LVGL trova il `lv_conf.h` dello sketch.
Se compare `lv_conf.h not found`, copia `firmware/ritmo_code/lv_conf.h` nella cartella
`libraries` di Arduino (un livello sopra `lvgl`), proprio **questo** file: il suo
`#include <stdint.h>` è protetto da `#ifndef __ASSEMBLY__`, senza il quale la compilazione dei file
`.S` di lvgl fallisce con `Error: unknown opcode or format name 'typedef'`.

Lo sketch di bring-up ha il suo script, `firmware/bringup/build.sh`, con un FQBN diverso.

I font del tema (JetBrains Mono e DejaVu Sans Mono per i simboli) si rigenerano con
`tools/gen_fonts.sh`.

---

## Primo avvio

Tutto dallo schermo e dal browser, senza ricompilare:

1. **Wi-Fi**: tocca la rete e scrivi la password con la tastiera a schermo (fino a 3 reti salvate).
2. **Token**: lo schermo mostra l'indirizzo del dispositivo (es. `http://192.168.1.42`). Aprilo da
   PC o telefono sulla stessa rete, dai un nome all'account (es. *Studio*) e **incolla il token**.
   Il dispositivo lo **verifica** subito con una chiamata reale prima di accettarlo.
3. **PIN**: scegli un PIN di 4 cifre (inserito due volte); il token viene cifrato con questo PIN.

Agli avvii successivi basta il **PIN**. Gli account aggiunti dopo (*Impostazioni → account*) usano
lo stesso modulo e lo stesso PIN.

---

## Sicurezza

- I token sono salvati **cifrati** (AES-256-GCM, chiave derivata dal PIN con SHA-256), uno slot NVS
  per account, tutti con **lo stesso PIN**. Il PIN **non viene mai salvato**: un PIN sbagliato fa
  fallire la verifica GCM.
- Dopo **10 tentativi** sbagliati le credenziali vengono **cancellate** e si torna al primo avvio
  (dopo ogni errore si attendono 15 secondi).
- Il PIN resta in RAM durante la sessione per cambiare account senza richiederlo; il token attivo è
  comunque già decifrato in RAM.
- Storico e ritmo orario stanno in **LittleFS**, un file per account (senza token).
- Il **pannello web** si legge senza password da chi è sulla tua rete locale: mostra percentuali,
  stato, nome dell'account, meteo e dati del PC, mai il token. Le **modifiche** dal browser (ID dei
  modelli, città, PC, prezzo dell'energia) e il **collegamento dell'app PC** richiedono il PIN (5
  errori bloccano per 5 minuti); l'**aggiornamento firmware** richiede il codice mostrato sullo schermo.
- L'app **Ritmo Code PC Monitor** espone in rete solo `/data.json` (niente nomi di file, processi o
  finestre; dei progetti di Claude Code solo il nome della cartella e la percentuale, delle sessioni
  aperte stato e titolo della scheda, mai i contenuti); la sua pagina di stato e il collegamento
  rispondono solo al PC stesso. Dal dispositivo accetta solo i comandi della pagina media e **apri
  sessione**, che porta davanti una finestra e al massimo preme Ctrl+PgGiù in Warp.
- `.env` e `.mcp.json` sono in `.gitignore`: **nessun segreto va su git**.

---

## Simulatore

Una copia fedele dell'interfaccia gira nel browser, con un pannello per simulare percentuali,
reset, errori, modelli e velocità del tempo:

```bash
python simulator/serve.py     # poi apri http://127.0.0.1:8480/simulator/
```

Per rigenerare le immagini di questo README (serve `puppeteer-core` e Chrome):

```bash
node tools/capture_screens.js
```

---

## Struttura del repository

```
firmware/
  ritmo_code/                 # il firmware (sketch arduino-cli)
    ritmo_code.ino            # setup/loop, stati, dashboard, schermate, server web
    status_page.h               # pannello web servito su "/"
    api.cpp/.h                  # fetchUsage() e sonda dei modelli
    extras.cpp/.h               # meteo (Open-Meteo) e statistiche del PC
    ota_guard.cpp               # conferma del firmware dopo l'aggiornamento (rollback)
    status.cpp/.h               # incidenti da status.claude.com
    crypto.cpp/.h               # AES-256-GCM + chiave dal PIN
    accounts.cpp/.h             # slot account in NVS
    certs.cpp/.h                # CA bundle per HTTPS
    wifi_manager.h              # reti salvate in NVS (fino a 3)
    touch.h                     # driver touch AXS15231B
    font_jbm_*.c                # font del tema Terminale (96 px orologio della home, 150 px orologio notturno)
    logo_assets.h               # Clawd e simboli (da assets/brand)
    config.h                    # pin, endpoint, costanti, versione
    lv_conf.h                   # configurazione LVGL 9.2
    partitions.csv              # 16 MB: due slot app (OTA) + nvs + LittleFS
    build.sh                    # compila / carica / monitor / ota
  bringup/                      # bring-up validato (riferimento hardware)
  RIFERIMENTO-HARDWARE-LVGL.md   # display, colori e touch che funzionano
simulator/                      # simulatore web dell'interfaccia
ritmo-code-pc-monitor/          # app Windows per le statistiche del PC
tools/
  capture_screens.js            # immagini del README dal simulatore
  gen_fonts.sh                  # font LVGL del tema
  gen_logo_assets.py            # SVG del brand -> logo_assets.h
assets/                         # schermate e brand (brand/)
3D Case/                        # case stampabili (STL)
flash.sh                        # compila e carica trovando da solo la porta (macOS)
```

---

## Crediti

**Ritmo Code** è sviluppato da **Luca Marullo · [Innova Design Studio](https://innovadesignstudio.it)**
([info@innovadesignstudio.it](mailto:info@innovadesignstudio.it)).

È basato su [**claude-usage-stick**](https://github.com/benevid/claude-usage-stick-SVGL) di
**Benevid Felix**, a sua volta derivato dal Claude Usage Stick originale di
[@oauramos](https://github.com/oauramos), con i contributi di
[@jzimath-lab](https://github.com/jzimath-lab), [@renanravelli](https://github.com/renanravelli),
[@mpsd18](https://github.com/mpsd18) e [@ViniciusLoureiro67](https://github.com/ViniciusLoureiro67).
Da lì arrivano la lettura dell'uso dagli header, la cifratura del token, il supporto multi-account
e la base hardware; interfaccia, pagine, funzioni e pannello web di questa versione sono stati
riscritti.

Non è un prodotto ufficiale Anthropic. Claude e Claude Code sono marchi di Anthropic.

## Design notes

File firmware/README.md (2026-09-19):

# firmware/ — Ritmo Code (ESP32-S3 + LVGL)

Firmware per il display touch **Guition JC4832W535** (AXS15231B QSPI, 480×320).

- **`ritmo_code/`** — il progetto. Sketch arduino-cli completo: recupera l'utilizzo di
  Claude (header di `api.anthropic.com`), lo stato dei modelli (`status.claude.com`)
  e visualizza tutto in LVGL 9 con navigazione touch. Token OAuth memorizzato cifrato
  (AES-256-GCM + PIN). Per la build vedi [`ritmo_code/build.sh`](ritmo_code/build.sh).
- **`bringup/`** — bring-up validato sull'hardware (colori corretti, orientamento
  con USB a sinistra e touch allineato). Riferimento noto-funzionante per la config di
  display/touch; non è l'app. Compila con il `build.sh` **di questa cartella**
  ([`bringup/build.sh`](bringup/build.sh)): usa `PartitionScheme=huge_app`
  (qui non c'è un `partitions.csv`) e riutilizza il `lv_conf.h` di `ritmo_code`;
  l'FQBN del firmware non va bene per questa cartella.
- **`RIFERIMENTO-HARDWARE-LVGL.md`** — pin, librerie testate, pipeline di flush
  (rotazione di 270° in senso orario fatta a mano) e trappole (PSRAM OPI obbligatoria, ecc.).

Parti da [`../README.md`](../README.md) per la panoramica generale e la procedura di build passo passo.

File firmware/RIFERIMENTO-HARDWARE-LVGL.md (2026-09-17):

# Riferimento Hardware & LVGL — Gadget Valorant

Estratto dal progetto già funzionante (`../esp32_controller/`). **Questa è la configurazione del display testata e validata**: va usata come base del firmware del gadget per non ripetere la fatica di azzeccare i colori.

---

## 0. ⭐ TL;DR — cosa fa funzionare i colori

La scheda ha un display **AXS15231B su QSPI**. Ciò che dà **colori corretti** (dopo molti tentativi) è:

1. `Arduino_Canvas` (framebuffer in RAM/PSRAM) creato con **`rotation = 0`** — commento nel codice originale: *"Canvas rotation=0 (perfect colors)"*.
2. La **rotazione in orizzontale è fatta manualmente nel flush** (ruota di 270° in senso orario, USB a sinistra), copiando i pixel dal buffer di LVGL nel framebuffer del Canvas.
3. L'invio al pannello è `gfx->flush()` (spinge l'intero Canvas via QSPI).

> ❌ **NON** usare l'approccio di `display.h.bak` (Canvas `rotation=1` + `draw16bitRGBBitmap` nel flush): è quello che dava **colori sbagliati**. La versione corretta è quella di `esp32_controller.ino`.

Perché funziona: `Arduino_AXS15231B` si aspetta il framebuffer nel formato nativo (verticale 320×480) senza rotazione interna; ruotare tramite il Canvas rimescolava l'ordine dei byte/colori. Tenendo il Canvas a `rotation=0` e ruotando "a mano" nel flush, i pixel RGB565 arrivano nell'ordine giusto.

---

## 1. Scheda & display

| | |
|---|---|
| Scheda | **Guition JC4832W535** (ESP32‑S3) |
| Flash / PSRAM | 16 MB flash · **8 MB PSRAM OPI** (obbligatoria) |
| Display | **AXS15231B**, interfaccia **QSPI**, **480×320** orizzontale (nativo 320×480 verticale) |
| Touch | **AXS15231B capacitivo**, I²C, addr `0x3B` |
| USB | CDC nativo (Serial direttamente sulla USB) |

## 2. Pin (`config.h`)

```
// Display QSPI (AXS15231B)
TFT_CS=45  TFT_SCK=47  TFT_SDA0=21  TFT_SDA1=48  TFT_SDA2=40  TFT_SDA3=39
TFT_BL=1 (backlight, HIGH=on)   TFT_TE=38
QSPI_FREQ = 40 MHz

// Touch I2C (AXS15231B)
TOUCH_SDA=4  TOUCH_SCL=8  TOUCH_INT=3  TOUCH_ADDR=0x3B

// SD Card SPI (probabilmente non la useremo — abbiamo LittleFS)
SD_CS=10  SD_MOSI=11  SD_SCLK=12  SD_MISO=13

SCREEN_WIDTH=480  SCREEN_HEIGHT=320
```

## 3. Librerie (versioni testate)

| Lib | Versione | Uso |
|---|---|---|
| `esp32` (core) | **3.3.11** | toolchain ESP32‑S3 |
| `GFX Library for Arduino` (Arduino_GFX) | **1.6.5** | driver QSPI + Canvas (`Arduino_ESP32QSPI`, `Arduino_AXS15231B`, `Arduino_Canvas`) |
| `lvgl` | **9.2.2** | UI (API v9: `lv_display_create`, ecc.) |
| `ArduinoJson` | **7.2.0** | parsing del payload del backend |
| `LittleFS`, `WiFi`, `Preferences` | builtin (core) | asset / rete / config NVS |

> È installata anche `LovyanGFX`, ma **non viene usata** su questa scheda: si usa Arduino_GFX.

---

## 4. ⭐ Inizializzazione del display (codice funzionante)

```cpp
#include <Arduino_GFX_Library.h>
#include <lvgl.h>

Arduino_Canvas *gfx = nullptr;
static uint16_t *canvas_fb = nullptr;   // framebuffer del Canvas (320x480)

// --- setup() ---
Arduino_DataBus *bus = new Arduino_ESP32QSPI(
    TFT_CS, TFT_SCK, TFT_SDA0, TFT_SDA1, TFT_SDA2, TFT_SDA3);
Arduino_GFX *g = new Arduino_AXS15231B(bus, GFX_NOT_DEFINED, 0, false, 320, 480);
gfx = new Arduino_Canvas(320, 480, g, 0, 0, 0);   // ⭐ rotation = 0

if (!gfx->begin(40000000UL)) { /* FATAL */ }
gfx->fillScreen(0x0000);
gfx->flush();
canvas_fb = gfx->getFramebuffer();                 // ⭐ accesso diretto al FB

pinMode(TFT_BL, OUTPUT);
digitalWrite(TFT_BL, HIGH);                         // backlight ON
```

### Flush callback (rotazione manuale 270° in senso orario — USB a sinistra)

```cpp
static void disp_flush_cb(lv_display_t *disp, const lv_area_t *area, uint8_t *px_map) {
    uint16_t *src = (uint16_t *)px_map;
    for (int ly = 0; ly < SCREEN_HEIGHT; ly++) {        // 320
        uint16_t *src_row = src + ly * SCREEN_WIDTH;    // 480
        for (int lx = 0; lx < SCREEN_WIDTH; lx++) {
            canvas_fb[(479 - lx) * 320 + ly] = src_row[lx];  // ruota di 270° CW
        }
    }
    gfx->flush();
    lv_disp_flush_ready(disp);
}
```

> Questo flush usa il **render mode FULL** (LVGL consegna l'intero schermo in una volta). Per questo il buffer di LVGL ha la dimensione dello schermo intero (480×320) e risiede nella **PSRAM**.

---

## 5. LVGL 9 — setup

```cpp
lv_init();
lv_tick_set_cb([]() -> uint32_t { return millis(); });   // tick tramite millis()

uint32_t bufSize = SCREEN_WIDTH * SCREEN_HEIGHT * sizeof(lv_color_t); // 480*320*2
lv_color_t *buf = (lv_color_t *)heap_caps_malloc(
    bufSize, MALLOC_CAP_SPIRAM | MALLOC_CAP_8BIT);       // ⭐ PSRAM

lv_display_t *disp = lv_display_create(SCREEN_WIDTH, SCREEN_HEIGHT); // 480x320
lv_display_set_flush_cb(disp, disp_flush_cb);
lv_display_set_buffers(disp, buf, NULL, bufSize, LV_DISPLAY_RENDER_MODE_FULL);

lv_indev_t *indev = lv_indev_create();
lv_indev_set_type(indev, LV_INDEV_TYPE_POINTER);
lv_indev_set_read_cb(indev, touch_read_cb);
```

Nel **loop**: `lv_task_handler();` + `delay(16);` (~60 fps). Aggiornare le schermate con dati live a intervalli (es. ogni 1 s).

### `lv_conf.h` (punti critici)
- `LV_COLOR_DEPTH 16` (RGB565).
- Abilitare i font Montserrat usati: 10, 12, 14, 18, 24, 28.
- `LV_USE_OS 0` (loop cooperativo) e tick tramite `lv_tick_set_cb` (vedi sopra).
- PSRAM: il buffer è allocato manualmente, quindi `LV_MEM_*` può restare al default (RAM interna) per il resto.

---

## 6. Touch (AXS15231B, I²C) — `touch.h`

- Driver custom (classe `AXS15231B_Touch`), I²C 400 kHz, INT su `FALLING`.
- Comando di lettura: `{0xB5,0xAB,0xA5,0x5A,0x00,0x00,0x00,0x08}` → legge 8 byte; X/Y nei byte 2–5.
- Istanziare con **rotation = 3** per l'orientamento "USB a sinistra":
  ```cpp
  AXS15231B_Touch touch_dev(TOUCH_SCL, TOUCH_SDA, TOUCH_INT, TOUCH_ADDR, 3);
  ```
- Mappatura (nativo verticale 320×480):
  ```
  rot 1 (orizz.):    x = raw_y;        y = 319 - raw_x
  rot 3 (USB-sin.):  x = 479 - raw_y;  y = raw_x
  ```

## 7. ⚠️ Orientamento — display e touch DEVONO combaciare

USB a sinistra → **il display ruota di 270° in senso orario nel flush** (`479 - lx`) **e** **touch rotation = 3**. Se se ne inverte uno senza l'altro, il tocco risulta specchiato/scambiato. Tenerli sempre in coppia.

---

## 8. WiFi — riutilizzare `wifi_manager.h` (quasi così com'è)

Classe `WiFiManager` pronta, memorizza fino a **3 reti nella NVS** (`Preferences` namespace `"wifi"`):

```cpp
g_wifi.begin();                       // carica le reti salvate (NVS)
bool ok = g_wifi.autoConnect(5000);   // prova quelle salvate, 5 s ciascuna
// se fallisce → schermata di config:
int n = g_wifi.scanNetworks(results, max);          // elenca le reti
g_wifi.connectTo(ssid, pass, 15000);  // connette E salva nella NVS (la porta in cima)
g_wifi.getIP(); g_wifi.getSSID(); g_wifi.getSavedSSID();
```

**Flusso nel firmware del gadget:** al boot, `begin()` → `autoConnect()`. Se non si connette, aprire la schermata WiFi (scan + tastiera LVGL per la password) → `connectTo()`. Riutilizzare `ui_wifi.cpp` come base della schermata.

## 9. Client HTTP — adattare `api_client.h`

Schema del riferimento (da mantenere): `HTTPClient` + `WiFiClientSecure` con `setInsecure()` per **HTTPS**, parsing con `ArduinoJson`.

**Differenza per il nostro gadget:** non c'è login email/password+JWT. Il gadget fa soltanto:
```cpp
GET https://<backend>/api/v1/gadget/dashboard
Header: Authorization: Bearer <DEVICE_TOKEN>   // il codice breve tipo "SV76-7KX2"
```
e fa il parsing del payload snello (vedi `../docs/03-CONTRATO-API.md`). Il device token viene digitato una sola volta sul gadget e salvato nella **NVS** (stesso schema `Preferences` del WiFi).

---

## 10. Build & upload (arduino-cli)

- **arduino-cli 1.4.1**, core **esp32:esp32 3.3.11** già installati.
- **Scheda collegata:** `/dev/cu.usbmodem101`.
- `partitions.csv` (16 MB): app0 2 MB + spiffs ~14 MB (LittleFS monta la partizione "spiffs").

FQBN consigliato (ESP32‑S3 + **PSRAM OPI** + 16 MB + partizione custom + **USB CDC**):
```bash
FQBN="esp32:esp32:esp32s3:PSRAM=opi,FlashSize=16M,PartitionScheme=custom,CDCOnBoot=cdc,USBMode=hwcdc,FlashMode=qio"

arduino-cli compile --fqbn "$FQBN" .
arduino-cli upload  --fqbn "$FQBN" -p /dev/cu.usbmodem101 .
arduino-cli monitor -p /dev/cu.usbmodem101 -c baudrate=115200
```
> `PartitionScheme=custom` usa il `partitions.csv` della cartella dello sketch. **PSRAM=opi è obbligatorio** (il framebuffer 480×320×2 ≈ 300 KB + il buffer LVGL non entrano nella RAM interna). Verificare i nomi esatti delle opzioni dell'FQBN con `arduino-cli board details --fqbn esp32:esp32:esp32s3` al momento della compilazione.

---

## 11. Sequenza di implementazione del firmware suggerita (Valorant)

> Ordine pensato per validare presto la parte difficile (display/colori/touch) e poi aggiungere il resto.

- **Fase 0 — Scheletro:** struttura dello sketch in `firmware/`, copiare `config.h` (pin), `touch.h`, `wifi_manager.h` dal riferimento; `lv_conf.h` con depth 16 + font.
- **Fase 1 — Bring-up (CRITICO):** ✅ **FATTO e validato sull'hardware** — sketch in `firmware/bringup/` (colori, orientamento USB a sinistra e touch 100% OK). È la base nota-funzionante da cui copiare la config di display/touch.
- **Fase 2 — Base LVGL + tema Valorant:** stili (colori `#0b0b18`/`#7c3aed`/`#f43f5e`), helper per label/pannello/pulsante (rispecchiare `ui_theme.h`).
- **Fase 3 — WiFi:** `autoConnect` + schermata di configurazione (scan + tastiera) riutilizzando `wifi_manager.h`/`ui_wifi.cpp`.
- **Fase 4 — Device token:** schermata di onboarding sul gadget (tastiera LVGL) → salva il codice breve nella NVS.
- **Fase 5 — API client:** `GET /gadget/dashboard` con il token → parsing del payload con `ArduinoJson`.
- **Fase 6 — Schermata Dashboard:** elo (immagine per `rank.id`), `lv_bar` degli RR, tendenza. Con dati reali.
- **Fase 7 — Navigazione + schermate 2–4:** `lv_tabview` con swipe → Cronologia, Grafico (`lv_chart`), Stato.
- **Fase 8 — Asset + stati:** icone di elo/agente su LittleFS (per id); caricamento / errore / "non aggiornato" (stale).
- **Fase 9 — Polling + extra:** aggiornare a ogni `poll` del payload; LED WS2812B opzionale (colore dell'elo / post-partita).

## 12. Adattamenti rispetto al riferimento (roaster)

| Riferimento (esp32_controller) | Gadget Valorant |
|---|---|
| BLE (`ble_roaster.h`) | ❌ rimuovere (non usato) |
| SD Card (`sd_storage.h`) | usare **LittleFS** (asset) + **NVS** (config) |
| Auth: email/password → JWT | **device token** (Bearer), senza login |
| Tema arancione industriale | **viola/rosso** (palette Valorant) |
| Schermate di tostatura/profili | Dashboard / Cronologia / Grafico / Stato |

## 13. Trappole (da ricordare)

- 🔴 **PSRAM OPI obbligatoria** — senza, l'`heap_caps_malloc` del framebuffer fallisce e la scheda si blocca al boot.
- 🔴 **Usare lo schema del `.ino`** (Canvas rot=0 + rotazione manuale nel flush), **non** quello del `.bak` — altrimenti colori sbagliati.
- 🔴 **USB CDC On Boot** abilitato, altrimenti `Serial` non compare sulla USB nativa.
- 🟡 Display e touch devono avere lo **stesso orientamento** (270°/rot=3 per USB a sinistra).
- 🟡 LVGL **9.2.x** — API nuova (`lv_display_create`, `lv_tick_set_cb`); gli esempi vecchi (v8) non compilano.

## 14. Trucchi e insidie di LVGL 9.2 (imparati nel redesign v2.x)

> Scoperti sul campo durante il redesign del 2026-07 (indicatore segmentato, sprite
> ufficiali, animazioni di soglia, i18n). Valgono per qualsiasi firmware di questa scheda.

- 🔴 **I font Montserrat integrati contengono solo ASCII + `°` (0xB0) + bullet `•` (0x2022).**
  Niente accenti né lineetta lunga (—): vengono resi come glifo mancante. Scrivere la UI senza
  accenti e usare il bullet UTF-8 (`"\xE2\x80\xA2"`) come separatore visivo.
- 🔴 **I prototipi automatici del `.ino` si rompono con i tipi personalizzati**: una funzione che
  restituisce `MeuStruct*` riceve un prototipo generato IN CIMA al file, prima della definizione dello
  struct → errore `'MeuStruct' does not name a type`. Soluzione: restituire un indice `int`
  (vedi `day_slot()` nello sketch) oppure usare solo tipi già noti (`lv_obj_t*` ecc.).
- 🟢 **Immagini integrate (ARGB8888)**: `lv_image_dsc_t` nella 9.2 accetta l'init posizionale
  `{{LV_IMAGE_HEADER_MAGIC, LV_COLOR_FORMAT_ARGB8888, 0, w, h, w*4, 0}, size, data}`
  (ordine little-endian verificato in `src/draw/lv_image_dsc.h`). Byte per pixel
  nell'ordine **B,G,R,A**. Pipeline: `tools/gen_logo_assets.py` (rsvg-convert + Pillow)
  rasterizza l'SVG → `logo_assets.h`.
- 🟢 **`lv_obj_set_style_image_recolor(+_opa)`** tinge lo sprite a runtime — usato per
  rendere Clawd grigio nello stato di errore senza generare un secondo asset.
- 🟡 **Animazioni procedurali nel `loop()` > `lv_anim`** per overlay che possono sparire in
  qualsiasi momento (il tocco li chiude): `lv_anim` con `exec_cb` custom che punta a oggetti
  eliminati = crash. Schema del firmware: tenere i puntatori in uno struct, animare in base al tempo
  (`millis()`) ed eliminare tutto insieme (`lv_obj_delete(scrim)`).
- 🟡 **Gli overlay devono vivere in `lv_layer_top()`** (sopravvivono agli aggiornamenti della schermata), ma
  vanno ripuliti manualmente a ogni cambio di stato (`lv_obj_clean(lv_layer_top())`
  in `render_state()`), altrimenti trapelano da una schermata all'altra.
- 🟡 **Area di tocco piccola**: oltre a ingrandire il pulsante, usare
  `lv_obj_set_ext_click_area(btn, px)` — l'ingranaggio dell'header usa 58×40 + 12px extra.
- 🟢 **i18n economico**: macro `#define TRS(pt, en) (g_lang ? (en) : (pt))` inline in ogni
  stringa (senza una tabella parallela che possa disallinearsi). Cambiare lingua = salvare in NVS +
  `request_state()` per ricostruire la schermata corrente.
- 🟢 **Gli occhi del Clawd ufficiale sono buchi trasparenti nel path** — su sfondo scuro
  sembrano già occhi; le espressioni diventano overlay (palpebre/X) posizionati tramite i define
  `CLAWD_*_EYE*` emessi dal generatore di asset.

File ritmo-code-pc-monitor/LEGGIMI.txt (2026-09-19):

Ritmo Code PC Monitor
=====================

Invia le statistiche di questo PC al dispositivo Ritmo Code (pagina "pc" e riga pc della home):
CPU, GPU, RAM, rete, dischi, temperature, consumi, ventole e sessioni di Claude Code.

INSTALLAZIONE
1) Copia questa cartella dove vuoi tenerla (es. C:\Programmi\RitmoCodePcMonitor).
2) Doppio clic su installa.bat e conferma i permessi di amministratore.
   - apre la porta 8765 solo alla rete locale
   - avvia LibreHardwareMonitor all'accesso (serve l'amministratore per i sensori)
   - avvia il monitor con Windows
3) Si apre http://127.0.0.1:8765/ : scegli il dispositivo, inserisci il PIN,
   premi "Collega questo PC". Il dispositivo deve essere acceso, sbloccato e sulla stessa rete.

FILE
RitmoCodePcMonitor.exe            con finestra: per verifiche
RitmoCodePcMonitor-nascosto.exe   senza finestra: quello avviato con Windows
LibreHardwareMonitor\             sensori (MPL-2.0), web server solo su 127.0.0.1:8085
disinstalla.bat                   toglie avvio automatico, attivita' e regola firewall

ICONA NELL'AREA DI NOTIFICA (vicino all'orologio)
- passandoci sopra: CPU, GPU, RAM e se il dispositivo sta leggendo i dati
- doppio clic: pagina di stato e collegamento
- clic destro: apri il pannello del dispositivo, esci
- clic destro -> Timer e pomodoro: avvia sul dispositivo un pomodoro o un timer, fermalo o salta la fase

AVVISI DI CLAUDE CODE
Nella pagina http://127.0.0.1:8765/ premi "Attiva gli avvisi": l'app aggiunge tre hook a
~/.claude/settings.json (il resto del file non cambia, copia in settings.json.ritmo-bak).
Dalle nuove sessioni di Claude Code il dispositivo mostra quando Claude ha finito o aspetta un
permesso. Quando mostrarli si sceglie sul dispositivo: Impostazioni -> avvisi claude code.
"Disattiva" li toglie.

CALENDARIO
Incolla il link segreto iCal (Google Calendar: Impostazioni del calendario -> Integra il
calendario -> Indirizzo segreto in formato iCal) nel pannello del dispositivo, pagina /home.
Questa app scarica gli eventi ogni 5 minuti e li passa al dispositivo; lo stato e' nella
pagina http://127.0.0.1:8765/ (riquadro calendario, "Aggiorna ora").

SUONI E NOTIFICHE
Quando il dispositivo mostra un avviso (fine del timer, pausa e ripresa del pomodoro, Claude ha
finito o aspetta, soglie di utilizzo) questo PC suona e mostra una notifica di Windows.
Nella pagina http://127.0.0.1:8765/ scegli suono, notifica e tipo di suono ("Prova" per sentirlo):
suoni di Windows (predefiniti, si sentono anche in desktop remoto) o melodie Ritmo Code.
Sul dispositivo: Impostazioni -> suoni sul pc. Di notte resta muto.

NOTE
- Windows SmartScreen puo' avvisare che l'app non e' riconosciuta (non e' firmata):
  "Ulteriori informazioni" -> "Esegui comunque".
- Temperature o watt vuoti: esci e rientra in Windows (LibreHardwareMonitor parte all'accesso
  come amministratore) oppure rilancia installa.bat.
- Se il dispositivo non vede il PC: stessa rete Wi-Fi? (il dispositivo usa solo il 2,4 GHz)
- Se l'IP del PC cambia, riapri http://127.0.0.1:8765/ e premi di nuovo "Collega questo PC",
  oppure riserva l'indirizzo del PC nel router.
- Per chiudere l'app: clic destro sull'icona -> Esci. Non avviare insieme la versione con
  finestra e quella nascosta: usano la stessa porta.
- installa.bat ferma e disattiva un eventuale LibreHardwareMonitor gia' installato da
  un'altra app (ne basta uno); disinstalla.bat lo riattiva.

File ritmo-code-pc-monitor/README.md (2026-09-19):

# Ritmo Code PC Monitor

Programma per Windows che invia le statistiche del PC al dispositivo **Ritmo Code**
(pagina **pc** e riga pc della **home**): CPU, GPU, RAM, rete, dischi, temperature, consumi, ventole,
uptime e sessioni di Claude Code aperte.

- Solo libreria standard di Python; i sensori hardware arrivano da
  [LibreHardwareMonitor](https://github.com/LibreHardwareMonitor/LibreHardwareMonitor) (MPL-2.0),
  incluso nel pacchetto e raggiungibile solo da questo PC (`127.0.0.1:8085`).
- Il dispositivo legge `http://<ip-del-pc>:8765/data.json` con l'intervallo scelto nelle sue
  impostazioni (1 s, 3 s, 5 s, 1 min). Niente passa da internet.
- Collegamento guidato: la pagina `http://127.0.0.1:8765/` trova il dispositivo sulla rete e gli
  comunica l'indirizzo del PC. Serve il PIN del dispositivo, che non viene salvato.
- **Icona nell'area di notifica**: il suggerimento mostra CPU, GPU, RAM e se il dispositivo sta
  leggendo i dati; doppio clic apre la pagina di stato, il menu (clic destro) apre anche il pannello
  del dispositivo ed esce dall'app.
- **Avvisi di Claude Code**: con **Attiva gli avvisi** nella pagina di stato l'app aggiunge tre hook a
  `~/.claude/settings.json` (`UserPromptSubmit`, `Stop`, `Notification`). Gli hook mandano l'evento a
  `127.0.0.1:8765/claude/...`, l'app lo inoltra subito al dispositivo (`POST /claude`) e lo espone
  anche in `/data.json`. Il dispositivo mostra quando Claude ha finito o aspetta un permesso.
- **Suoni e notifiche**: quando il dispositivo mostra un avviso (timer, pomodoro, Claude Code, soglie) lo
  manda a `POST /notify` (accettato solo dal dispositivo collegato) e il PC suona e mostra una notifica di
  Windows. Suono, notifica e volume si scelgono nella pagina di stato (pulsante **Prova**).

## Uso

La guida completa, con problemi comuni e aggiornamento, è nel
[README principale](../README.md#installazione-su-windows).

1. `build_exe.bat` crea il pacchetto in `dist\` (serve Python 3.8+ e `pip install pyinstaller`; se
   manca LibreHardwareMonitor lo scarica `scarica_librehardwaremonitor.ps1`).
2. Copia `dist\` in una cartella fissa sul PC da monitorare ed esegui **`installa.bat`** (chiede
   l'amministratore): regola firewall sulla porta 8765 per la rete locale, LibreHardwareMonitor
   all'accesso, monitor all'avvio di Windows.
3. Nella pagina che si apre scegli il dispositivo, inserisci il PIN e premi **Collega questo PC**.

`disinstalla.bat` rimuove tutto. Da sorgente: `python ritmo_pc_monitor.py` (`--print` per una
lettura di prova, `--port`, `--interval`, `--no-lhm`, `--no-tray`).

## Dati inviati (`/data.json`)

| Campo | Fonte |
|---|---|
| `cpu_load`, `cpu_mhz`, `ram_load`, `ram_used_mb`, `ram_total_mb` | Windows |
| `net_down_bps`, `net_up_bps`, `disk_read_bps`, `disk_write_bps` | contatori di Windows |
| `disks` (lettera, % usata, GB liberi), `uptime_s`, `cpu_name` | Windows |
| `claude_sessions` | processi `claude.exe` avviati da un altro programma |
| `cpu_temp`, `cpu_power`, `cpu_core_max`, `cpu_voltage` | LibreHardwareMonitor |
| `gpu_name`, `gpu_load`, `gpu_temp`, `gpu_power`, `gpu_hotspot`, `gpu_mem_temp`, `gpu_clock_mhz`, `gpu_mem_load`, `vram_used_mb`, `vram_total_mb` | LibreHardwareMonitor (GPU con piu' memoria) |
| `fans`, `board_temps`, `ram_temps`, `storage` (temperatura e vita residua) | LibreHardwareMonitor (scheda madre, RAM, dischi) |
| `cc_busy`, `cc_ev_id`, `cc_ev` (`busy`, `done`, `perm`, `ask`), `cc_ev_proj`, `cc_ev_dur`, `cc_ev_age` | hook di Claude Code (solo se attivati) |

La pagina di stato e il collegamento rispondono solo a `127.0.0.1`; dalla rete e' leggibile solo
`/data.json`, che non contiene nomi di file, processi o finestre. Con gli avvisi di Claude Code attivi
contiene anche il nome della cartella dell'ultimo progetto (`cc_ev_proj`).

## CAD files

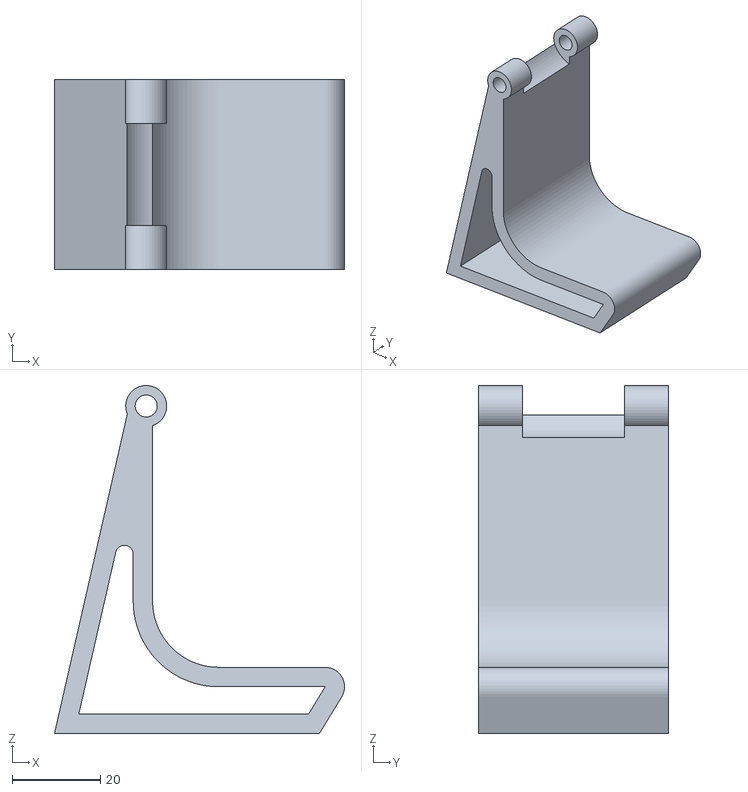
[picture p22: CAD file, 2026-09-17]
3D Case/Articolato/ClowDeck-Base.stl
65.7 x 43.0 x 78.8

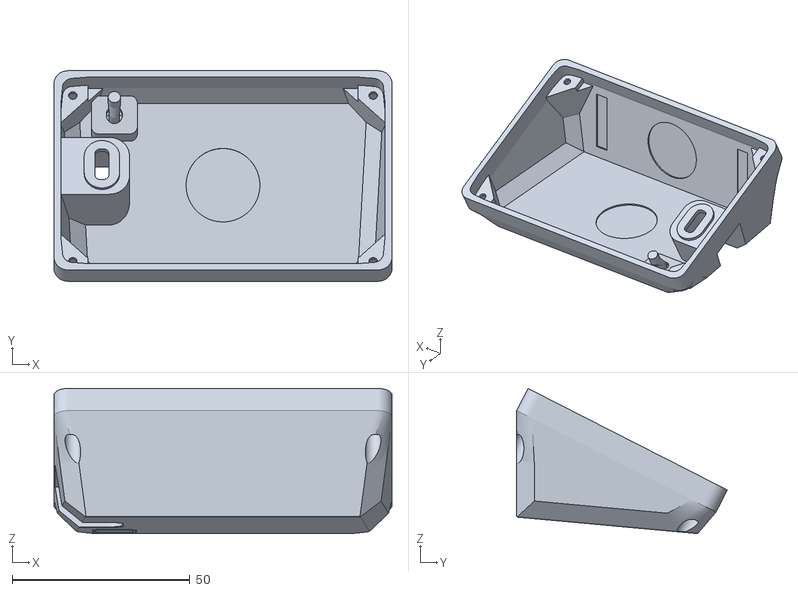
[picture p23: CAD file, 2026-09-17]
3D Case/Case_JC3248W535C.stl
95.2 x 59.3 x 40.9

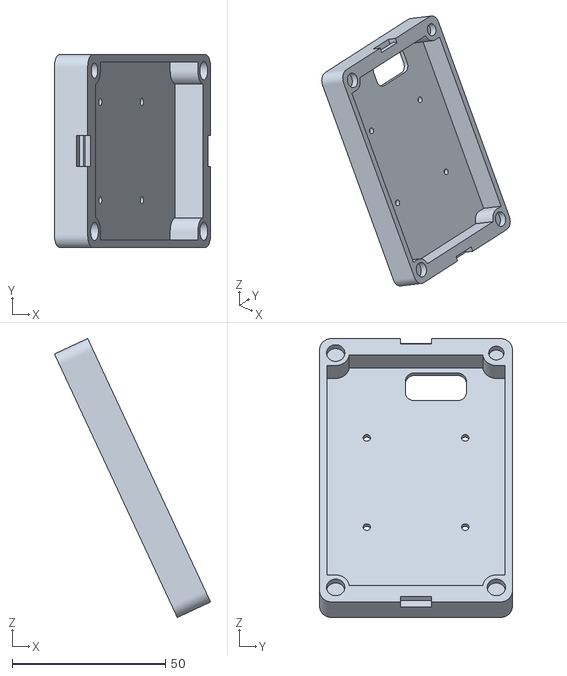
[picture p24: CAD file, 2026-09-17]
3D Case/Articolato/ClowDeck-Case.stl
51.0 x 63.0 x 91.2

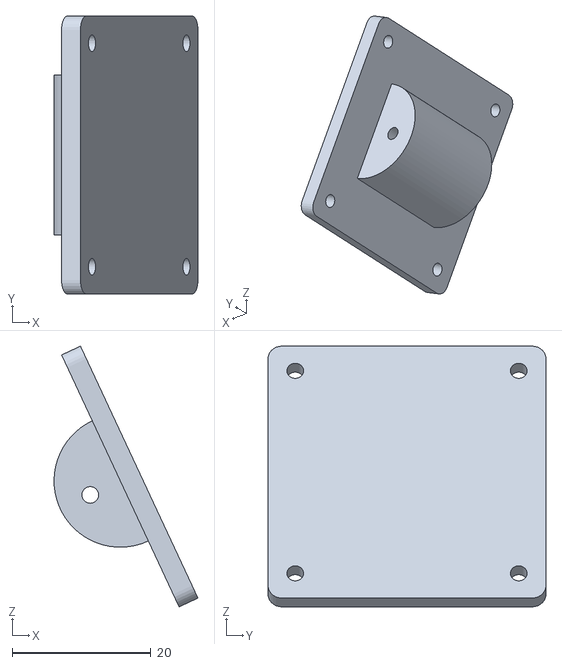
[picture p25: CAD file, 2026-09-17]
3D Case/Articolato/ClowDeck-Giunto.stl
20.7 x 40.0 x 37.5

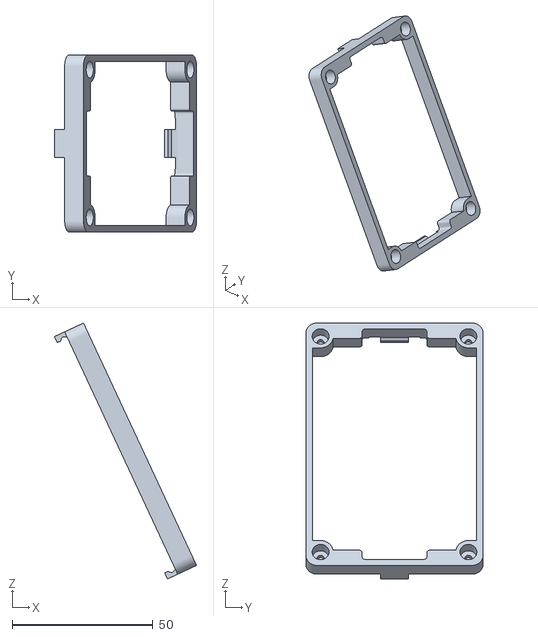
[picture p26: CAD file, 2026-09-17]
3D Case/Articolato/ClowDeck-Case-Display-Holder.stl
50.5 x 63.0 x 90.9

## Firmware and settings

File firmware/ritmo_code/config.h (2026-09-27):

#ifndef CONFIG_H
#define CONFIG_H

// ============================================================
// Ritmo Code — Guition JC4832W535 (ESP32-S3, AXS15231B)
// Pin: vedi firmware/RIFERIMENTO-HARDWARE-LVGL.md (bring-up validato)
// ============================================================

// ── Firmware ─────────────────────────────────────────────
#define FW_VERSION              "3.9.12"
#define GITHUB_REPO             "lucamar90/ritmo-code"   // aggiornamenti: ultima release di GitHub

// ── Display QSPI (AXS15231B) ─────────────────────────────
#define TFT_CS    45
#define TFT_SCK   47
#define TFT_SDA0  21
#define TFT_SDA1  48
#define TFT_SDA2  40
#define TFT_SDA3  39
#define TFT_BL    1
#define TFT_TE    38

#define SCREEN_WIDTH   480
#define SCREEN_HEIGHT  320
// Provato 80 MHz sulla scheda (set 2026): immagine leggermente sdoppiata, il bus
// non regge. Il clock SPI dell'ESP32 non ha valori intermedi (80 / 40 / 26.7...),
// quindi 40 MHz e' il massimo stabile.
#define QSPI_FREQ      40000000UL

// ── Touch I2C (AXS15231B) ────────────────────────────────
#define TOUCH_SDA  4
#define TOUCH_SCL  8
#define TOUCH_INT  3
#define TOUCH_ADDR 0x3B
// rotation=3 = USB a sinistra (coerente con il flush 270° CW)
#define TOUCH_ROTATION 3

// ── Polling ──────────────────────────────────────────────
#define DEFAULT_POLL_SEC        120
#define MIN_POLL_SEC            30
#define MAX_POLL_SEC            1800     // fino a 30 min (meno richieste alla API)
#define STATUS_POLL_SEC         300      // status.claude.com ogni 5 min

// Home: citta' predefinita del meteo (modificabile dal browser su /home) e PC con Ritmo Code PC Monitor
#define DEFAULT_WX_CITY         "Milano"
#define DEFAULT_WX_LAT          45.4643f
#define DEFAULT_WX_LON          9.1895f
#define DEFAULT_PC_HOST         ""        // lo imposta l'app Ritmo Code PC Monitor ("Collega questo PC") o /home

// ── Sicurezza (PIN + AES-256-GCM) ────────────────────────
#define PIN_LEN                 4
#define MAX_PIN_ATTEMPTS        10
#define LOCKOUT_SEC             15       // attesa fissa dopo ogni errore (il tetto vero sono i 10 tentativi)
#define KDF_ROUNDS              10000

// ── Rete / API Claude ────────────────────────────────────
#define WIFI_CONNECT_TIMEOUT_MS 8000
#define API_TIMEOUT_MS          15000
#define MESSAGES_ENDPOINT       "https://api.anthropic.com/v1/messages"
#define ANTHROPIC_VERSION       "2023-06-01"
// Con il token di Claude Code l'API accetta i modelli oltre Haiku solo da "Claude Code":
// senza questo prompt di sistema risponde con un 429 finto, con uno User-Agent vecchio
// con 400 ("version X or newer is required"). Alzare CLAUDE_CODE_UA quando lo chiede.
#define CLAUDE_CODE_UA          "claude-code/2.1.281"
#define CLAUDE_CODE_SYSTEM      "You are Claude Code, Anthropic's official CLI for Claude."
#define PROBE_MODEL             "claude-haiku-4-5-20251001"
// status.anthropic.com reindirizza qui — interrogare direttamente l'host canonico
#define STATUS_ENDPOINT         "https://status.claude.com/api/v2/incidents/unresolved.json"

// NTP (necessario per i contatori di reset)
#define NTP_SERVER_1            "pool.ntp.org"
#define NTP_SERVER_2            "time.cloudflare.com"

// ── NVS ──────────────────────────────────────────────────
#define NVS_NAMESPACE           "claude"

#endif // CONFIG_H

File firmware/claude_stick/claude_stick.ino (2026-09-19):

/**
 * Ritmo Code — monitor d'uso per Claude Code, schermo touch LVGL
 * Scheda: Guition JC4832W535 (ESP32-S3, AXS15231B QSPI), 480x320 orizzontale.
 *
 * Dashboard del rate-limit di Claude Code (finestre 5h e 7g, header unified-*),
 * sonda reale per modello (latenza + HTTP), proiezione di esaurimento della
 * finestra 5h e ritmo d'uso orario con filtro di periodo. Token OAuth inserito
 * sullo schermo e salvato cifrato (AES-256-GCM, chiave derivata da un PIN di 4 cifre).
 *
 * Nessun pulsante fisico: navigazione 100% touch (swipe tra le schermate + slideshow).
 * Init di display/touch validato nel bring-up (vedi RIFERIMENTO-HARDWARE-LVGL.md).
 */
#include <Arduino.h>
#include <Arduino_GFX_Library.h>
#include <lvgl.h>
#include <display/lv_display_private.h>   // perf_label / timer del contatore FPS
#include <Wire.h>
#include <WiFi.h>
#include <WebServer.h>
#include <Update.h>
#include <esp_ota_ops.h>
#include <ESPmDNS.h>
#include <Preferences.h>
#include <LittleFS.h>
#include <time.h>
#include <math.h>
#include "config.h"
#include "touch.h"
#include "wifi_manager.h"
#include "api.h"
#include "status.h"
#include "crypto.h"
#include "accounts.h"
#include "extras.h"         // meteo (Open-Meteo) e statistiche del PC per la home
#include "status_page.h"   // pagina di stato servita su /
#include "logo_assets.h"   // Clawd + logotipo ufficiali (generato da tools/gen_logo_assets.py)
struct NoticeText;                 // avviso a schermo intero (prototipi generati da Arduino)

// ---- Tema "Terminale": font JetBrains Mono (tools/gen_fonts.sh) ----
// 12/14 Regular, 22 Medium, 54 ExtraBold (solo cifre e %). I simboli che JetBrains
// Mono non ha (✻ ↻ ↵ ✎ e lo spinner di Claude Code) arrivano da DejaVu Sans Mono;
// i LV_SYMBOL_* della tastiera LVGL dal fallback Montserrat.
LV_FONT_DECLARE(font_jbm_12)
LV_FONT_DECLARE(font_jbm_14)
LV_FONT_DECLARE(font_jbm_22)
LV_FONT_DECLARE(font_jbm_54)
LV_FONT_DECLARE(font_jbm_96)
LV_FONT_DECLARE(font_jbm_150)
#define F12 (&font_jbm_12)
#define F14 (&font_jbm_14)
#define F22 (&font_jbm_22)
#define F54 (&font_jbm_54)
#define F96 (&font_jbm_96)                  // orologio: solo cifre, due punti e trattino
#define F150 (&font_jbm_150)                // orologio notturno a tutto schermo
#define U_SPARK   "\xE2\x9C\xBB"   // ✻
#define U_REFRESH "\xE2\x86\xBB"   // ↻
#define U_MENU    "\xE2\x89\xA1"   // ≡
#define U_LEFT    "\xE2\x86\x90"   // ←
#define U_ENTER   "\xE2\x86\xB5"   // ↵
#define U_BKSP    "\xE2\x8C\xAB"   // ⌫
#define U_BLOCK   "\xE2\x96\x88"   // █
#define U_CURSOR  "\xE2\x96\x8C"   // ▌
#define U_MIDDOT  "\xC2\xB7"       // ·
#define U_PENCIL  "\xE2\x9C\x8E"   // ✎
#define U_CROSS   "\xE2\x9C\x95"   // ✕

// ---- Palette tema Terminale (stile Claude Code) ----
// Fondo terminale caldo, cornici a 1 px, un solo accento argilla; verde/ambra/rosso
// solo per lo stato.
#define C_BG       0x141413
#define C_SURFACE  0x1B1A18   // tasti e campi di testo
#define C_SURFACE2 0x23221F   // stato "premuto"
#define C_TRACK    0x2C2A27   // blocchi spenti
#define C_GRID     0x2C2A27   // griglie tratteggiate
#define C_BORDER   0x3A3834   // cornici
#define C_TEXT     0xE8E6DF
#define C_MUTED    0x8E8B82
#define C_FAINT    0x5C5A55
#define C_ACCENT   0xD97757   // argilla Claude
#define C_OK       0x9BC08A
#define C_WARN     0xE0B25A
#define C_BAD      0xE06C5A
#define C_BLUE     0x7DB9D6

// ---- Lingua (0 = italiano, 1 = english; Impostazioni -> NVS "lang") ----
// I font JetBrains Mono includono Latin-1: a schermo le lettere accentate ci sono.
static uint8_t g_lang = 0;
#define TRS(pt, en) (g_lang ? (en) : (pt))

// barra a blocchi: due label affiancate (piena + vuota) nello stesso font mono.
// Definita qui in cima: il preprocessore Arduino genera i prototipi prima del codice.
struct Blocks { lv_obj_t *on, *off; int n; };

// ---- Hardware ----
Arduino_Canvas *gfx = nullptr;
static uint16_t *canvas_fb = nullptr;
AXS15231B_Touch touch_dev(TOUCH_SCL, TOUCH_SDA, TOUCH_INT, TOUCH_ADDR, TOUCH_ROTATION);
WiFiManager g_wifi;
Preferences g_prefs;

// ---- Stato dell'applicazione ----
enum State {
  ST_BOOT, ST_PIN, ST_SETUP_PIN, ST_WIFI, ST_TOKEN,
  ST_LOADING, ST_MAIN, ST_SETTINGS, ST_ACCOUNTS, ST_ACCT_NAME, ST_ABOUT, ST_ERROR,
  ST_MODELS, ST_MODEL_EDIT, ST_OTA, ST_NETWORKS
};
static State g_state = ST_BOOT;
static State g_pending = ST_BOOT;
static bool  g_dirty = false;
static void request_state(State s) { g_pending = s; g_dirty = true; }

// ---- Dati ----
static UsageData   g_usage = {};
static ModelStatus g_status = {true, true, true, true, false};

// ---- Modelli sondati (1 per ciclo, a rotazione) ----
// Gli ID si cambiano dal browser (http://<ip>/models) o dal touch (Impostazioni ->
// Modelli) e restano in NVS ("mid0".."mid3"): quando Anthropic rinomina un modello
// basta aggiornare l'ID, senza riflashare. Il nome mostrato resta fisso perche' e'
// legato all'accessorio della mascotte. Nessuna richiesta in piu' alla API: la
// modifica azzera solo il risultato della sonda, che si rifa' al suo turno.
#define NMODELS 4
#define MODEL_ID_MAX 48
struct ModelInfo {
  const char *name; const char *defId; char id[MODEL_ID_MAX]; ProbeResult pr; uint32_t atMs;
  uint16_t lh[7]; uint8_t lhN;          // ultime latenze (mini-linea nella pagina Modelli)
};
static ModelInfo g_models[NMODELS] = {
  {"Haiku",  "claude-haiku-4-5-20251001", "", {0, 0}, 0},
  {"Sonnet", "claude-sonnet-5",           "", {0, 0}, 0},
  {"Opus",   "claude-opus-5",             "", {0, 0}, 0},
  {"Fable",  "claude-fable-5-1",          "", {0, 0}, 0},
};
static int g_probeIdx = 0;

// ---- Rete in background (task FreeRTOS sul core 0) ----
// Le chiamate HTTPS (utilizzo, status.claude.com, sonda modello) bloccavano il
// loop per 2-5 s: niente swipe ne' tocchi durante l'aggiornamento. Ora le esegue
// net_task sul core 0 (dove gira gia' lo stack WiFi), mentre LVGL resta libero sul
// core 1. Il task NON tocca mai LVGL, NVS o LittleFS: riempie g_net e alza
// g_netDone; il loop applica i risultati nel proprio thread (net_apply).
struct NetJob {
  // richiesta: scritta dal loop prima di svegliare il task
  char token[200];
  char modelId[MODEL_ID_MAX];
  int  modelIdx;
  uint32_t epoch;          // g_dataEpoch al momento della richiesta
  bool firstLoad;          // true = schermata di caricamento
  // risultato: scritto dal task
  UsageData usage;
  bool usageOk;
  ModelStatus status;
  bool statusOk;
  ProbeResult probe;
  bool probed;
  uint32_t durMs;
};
static NetJob g_net;
static TaskHandle_t g_netTask = nullptr;
static volatile bool g_netBusy = false;   // richiesta in corso (il task possiede g_net)
static volatile bool g_netDone = false;   // risultato pronto da applicare
static bool g_loadPending = false;        // ST_LOADING in attesa che il task sia libero
// Cambia quando token/account cambiano (switch, nuovo token, reset): un risultato
// partito prima appartiene ai dati vecchi e va scartato.
static uint32_t g_dataEpoch = 0;

// ID accettato: 3..47 caratteri a-z 0-9 . - _ (finisce dentro il JSON della sonda)
static bool model_id_valid(const char *v) {
  size_t n = strlen(v);
  if (n < 3 || n >= MODEL_ID_MAX) return false;
  for (size_t i = 0; i < n; i++) {
    char c = v[i];
    if (!((c >= 'a' && c <= 'z') || (c >= '0' && c <= '9') || c == '-' || c == '.' || c == '_'))
      return false;
  }
  return true;
}
static void model_key(int i, char *key, size_t sz) { snprintf(key, sz, "mid%d", i); }
static void models_load() {
  for (int i = 0; i < NMODELS; i++) {
    char key[8]; model_key(i, key, sizeof(key));
    String v = g_prefs.isKey(key) ? g_prefs.getString(key, "") : String();
    strlcpy(g_models[i].id, (v.length() && model_id_valid(v.c_str())) ? v.c_str() : g_models[i].defId,
            MODEL_ID_MAX);
  }
}
// Imposta l'ID del modello i. Vuoto = torna al predefinito. Toglie spazi e
// maiuscole (copia-incolla dalla documentazione). false = ID non valido.
static bool model_set_id(int i, const char *raw) {
  if (i < 0 || i >= NMODELS || !raw) return false;
  char v[MODEL_ID_MAX + 1];
  size_t n = 0;
  for (const char *c = raw; *c; c++) {
    if (*c == ' ' || *c == '\t' || *c == '\r' || *c == '\n') continue;
    if (n >= MODEL_ID_MAX) return false;               // troppo lungo
    v[n++] = (*c >= 'A' && *c <= 'Z') ? (char)(*c + 32) : *c;
  }
  v[n] = 0;
  char key[8]; model_key(i, key, sizeof(key));
  const char *next;
  if (!v[0] || !strcmp(v, g_models[i].defId)) {
    if (g_prefs.isKey(key)) g_prefs.remove(key);
    next = g_models[i].defId;
  } else {
    if (!model_id_valid(v)) return false;
    g_prefs.putString(key, v);
    next = v;
  }
  if (strcmp(next, g_models[i].id) != 0) {
    strlcpy(g_models[i].id, next, MODEL_ID_MAX);
    g_models[i].pr.code = 0; g_models[i].pr.ms = 0;   // "--" fino alla prossima sonda
    g_models[i].atMs = 0;
    g_models[i].lhN = 0;
    Serial.printf("[MODEL] %s -> %s\n", g_models[i].name, g_models[i].id);
  }
  return true;
}


// ---- Token / sicurezza ----
static AccountSlots g_accts;
static EncryptedBlob g_blob;
static bool g_hasToken = false;              // esiste un account salvato in NVS
static bool g_onboarding = false;            // primo setup in corso
static char g_token[200] = {0};              // token decifrato (solo in RAM)
static char g_pendingToken[200] = {0};       // token inserito, in attesa del PIN
// PIN di sessione: resta in RAM dallo sblocco fino al riavvio, perche' cambiare account
// e aggiungerne uno richiedono di decifrare/cifrare ALTRI slot senza richiedere il PIN.
// Compromesso accettato: non indebolisce il modello — il token vive GIA' decifrato in
// g_token, quindi chi riesce a leggere la RAM ha gia' cio' che conta. Resta valido
// che: niente di tutto questo finisce in NVS, e factory_reset() azzera questo buffer.
static char g_sessionPin[PIN_LEN + 1] = {0};
static int  g_tokenTargetSlot = 0;
static char g_pendingLabel[ACCT_LBL_MAX] = {0};
static char g_pinEntry[PIN_LEN + 1] = {0};   // cifre in digitazione
static char g_pinFirst[PIN_LEN + 1] = {0};   // 1° inserimento nel setup del PIN
static bool g_pinConfirming = false;         // setup: conferma (2° inserimento)
static int  g_pinAttempts = 0;               // tentativi errati (persistito)
static uint32_t g_lockoutUntil = 0;          // millis fino al prossimo tentativo consentito
static bool g_timeInit = false;

// ---- Refresh in background ----
static bool g_wantRefresh = false;        // il pulsante di refresh ha chiesto un aggiornamento
static bool g_refreshing = false;         // richiesta in corso
static bool g_lastFetchOk = true;         // l'ultimo fetch e' andato a buon fine?
static uint32_t g_lastOkMs = 0;           // millis dell'ultimo successo (per "aggiornato Xs fa")
static lv_obj_t *g_hdrStatus = nullptr;   // testo di stato nell'intestazione del dashboard

// ---- Fuso orario ----
// TZ_ROME usa la regola POSIX CET/CEST: l'ora legale cambia da sola (ultima
// domenica di marzo / ottobre). Gli altri valori sono offset GMT fissi.
#define TZ_ROME     99
#define TZ_ROME_RULE "CET-1CEST,M3.5.0,M10.5.0/3"

// ---- Luminosita' ----
static const uint8_t BRI_LEVELS[3] = {60, 160, 255};
static int g_briIdx = 1;

static uint32_t g_lastPollMs = 0;         // millis dell'ultimo poll (per la barra di refresh)
static int g_pollSec = DEFAULT_POLL_SEC;  // intervallo di aggiornamento (config, NVS)
static int g_tzOffset = TZ_ROME;          // fuso: TZ_ROME (ora legale auto) o offset GMT fisso, NVS
static int g_slideSec = 0;                // slideshow: 0=off, 5/10/15/30s (config, NVS)
static int g_heatMode = 3;                // 0=oggi 1=7g 2=30g 3=tutto (config, NVS)
static bool g_resetAlert = true;          // avviso quando una finestra oltre l'80% si libera (NVS "rstal")
static int  g_ccAlert = 2;                // avvisi di Claude Code: 0 spento, 1 sempre, 2/3 fine lavoro oltre 1/5 min (NVS "ccal")

// ---- Diagnostica prestazioni (Impostazioni -> Contatore FPS, NVS "perf") ----
// A schermo: overlay LVGL "FPS, CPU / ms (render | flush)". Sul seriale ogni 2s:
// fps, tempo di rotazione del frame, tempo di invio QSPI, loop piu' lento e
// memoria libera. Il tempo delle chiamate di rete viene stampato a ogni refresh.
// Nota: con il render FULL anche l'overlay stesso forza un ridisegno ogni ~300ms.
static bool g_perfOn = false;
struct PerfStats {
  uint32_t frames;
  uint64_t rotUs, copyUs, waitUs, txUs;
  uint32_t rotMaxUs, copyMaxUs, waitMaxUs, txMaxUs;
  uint32_t txFrames;       // frame inviati dal task del display (core 0)
  uint32_t loopMaxMs;
};
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
void loop() {
  lv_task_handler();
  perf_tick();
  spin_tick();

  // Server web (token durante l'onboarding; /models sul dashboard)
  if (g_web) {
    g_web->handleClient();
    if (g_state == ST_TOKEN && g_tokenGot) {
      g_tokenGot = false;
      if (g_onboarding || !g_sessionPin[0]) request_state(ST_SETUP_PIN);
      else finalize_pending_token();
    }
  }
  ota_tick();
  ota_health_tick();

  if (g_dirty) {
    g_dirty = false;
    render_state();
    g_loadPending = (g_state == ST_LOADING);   // il caricamento parte appena il task e' libero
  }

  // Rete in background: avvio del primo caricamento, risultati pronti, poll/refresh
  if (g_loadPending && g_state == ST_LOADING && net_start(true)) g_loadPending = false;
  if (g_netDone) net_apply();
  screen_tick();
  night_clock_sync();
  tm_tick();
  // home: meteo ogni 30 min (nuovo tentativo dopo 5 min se fallisce), PC ogni 5 s se la home e' visibile
  if (g_wxDone) {
    g_wxDone = false;
    if (g_wxRes.ok) { g_wx = g_wxRes; g_wxAtMs = millis(); }
    home_redraw();
  }
  if (g_pcDone) {
    g_pcDone = false;
    g_pc = g_pcRes;
    if (g_pc.ok) {
      g_pcAtMs = millis();
      if (g_pc.ccId) cc_event(g_pc.ccId, g_pc.ccEv, g_pc.ccProj, g_pc.ccDur, g_pc.ccAge);
    }
    if (g_pc.ok) {                                   // il grafico avanza a ogni lettura
      g_pcHistAtMs = millis();
      float v[3] = {g_pc.cpu, g_pc.gpu, g_pc.ram};
      if (g_pcHistN == PC_HIST) { for (int k = 0; k < 3; k++) memmove(g_pcHist[k], g_pcHist[k] + 1, PC_HIST - 1); g_pcHistN--; }
      for (int k = 0; k < 3; k++) g_pcHist[k][g_pcHistN] = (uint8_t)(v[k] < 0 ? 0 : (v[k] > 100 ? 100 : v[k] + 0.5f));
      g_pcHistN++;
    }
    pc_redraw();
    home_redraw();
  }
  if (g_state == ST_MAIN && g_wifi.isConnected() && g_screenMode < 2 && !g_wxReq && !g_wxDone && g_wxLat != 0) {
    bool due = g_wx.ok ? millis() - g_wxAtMs > 30UL * 60UL * 1000UL : (g_wxTryMs == 0 || millis() - g_wxTryMs > 5UL * 60UL * 1000UL);
    if (due) { g_wxTryMs = millis(); g_wxReq = true; }
  }
  if (g_state == ST_MAIN && g_pcHost[0] && g_screenMode < 2 && !g_pcReq && !g_pcDone &&
      millis() - g_pcTryMs >= PC_INT_S[g_pcIntIdx] * 1000UL - 50) {
    g_pcTryMs = millis();
    strlcpy(g_pcReqHost, g_pcHost, sizeof(g_pcReqHost));
    g_pcReq = true;
  }
  if (g_state == ST_MAIN && !g_netBusy && (g_wantRefresh || !polling_paused()) &&
      (g_wantRefresh || millis() - g_lastPollMs > (uint32_t)g_pollSec * 1000)) {
    if (net_start(false)) g_wantRefresh = false;
  }

  // Aggiornamento continuo: contatori (1s), barra di refresh (250ms), mascotte,
  // slideshow (5s, pausa di 10s dopo qualsiasi tocco)
  if (g_state == ST_MAIN) {
    uint32_t now = millis();
    static uint32_t lastTick = 0, lastBar = 0, lastBob = 0, blinkAt = 0;
    static bool blinkClosed = false;
    if (now - lastTick > 1000) { lastTick = now; dash_tick(); home_tick(); if (g_tmMode) set_hdr_status(); }
    if (now - lastBar > 1000 && g_ui.refBar) {       // filo del refresh: al massimo 1 ridisegno/s
      lastBar = now;
      const int W = 275;
      int v;
      if (g_refreshing) v = W;
      else if (polling_paused()) v = 0;
      else {
        uint32_t el = now - g_lastPollMs, per = (uint32_t)g_pollSec * 1000;
        v = el >= per ? 0 : (int)(W - (uint64_t)el * W / per);
      }
      if (v != lv_obj_get_width(g_ui.refBar)) lv_obj_set_width(g_ui.refBar, v);   // solo se cambia
    }
    // cursore ▌ della riga di prompt: lampeggia solo sulla pagina Ora
    static uint32_t lastCur = 0;
    if (g_ui.agCursor && g_curTile == 1 && now - lastCur > 700 && now - g_lastTouchMs > 400) {
      lastCur = now;
      if (lv_obj_has_flag(g_ui.agCursor, LV_OBJ_FLAG_HIDDEN)) lv_obj_clear_flag(g_ui.agCursor, LV_OBJ_FLAG_HIDDEN);
      else                                                     lv_obj_add_flag(g_ui.agCursor, LV_OBJ_FLAG_HIDDEN);
    }
    // Le mascotte vivono solo sulla pagina Modelli: animarle altrove (o mentre si
    // scorre) costava ridisegni continui senza che nessuno le vedesse.
    bool mascLive = (g_curTile == 2) && (now - g_lastTouchMs > 400) && !g_mo.scrim;
    if (mascLive && now - lastBob > 80) {           // animazione in base all'umore
      lastBob = now;
      float ph = now / 600.0f;
      for (int i = 0; i < g_mascN; i++) {
        if (!g_masc[i].cont) continue;
        if (g_masc[i].mood == 1)                    // ok: ondeggia allegro
          lv_obj_set_y(g_masc[i].cont, g_masc[i].baseY + (int)(2.0f * sinf(ph + i * 0.9f) - 1.0f));
        else if (g_masc[i].mood == 2) {             // limitato: ondeggio corto + sudore
          lv_obj_set_y(g_masc[i].cont, g_masc[i].baseY + (int)(1.2f * sinf(ph * 0.6f + i)));
          if (g_masc[i].drop) {
            uint32_t cyc = (now + i * 300) % 900;
            lv_obj_set_y(g_masc[i].drop, 6 + (int)(cyc * 22 / 900));
            lv_obj_set_style_bg_color(g_masc[i].drop, lv_color_mix(lv_color_hex(C_BLUE), lv_color_hex(C_BG),
                                                                   (uint8_t)(255 - cyc * 190 / 900)), 0);
          }
        }
      }
    }
    uint32_t bp = blinkClosed ? 150 : 3000;
    if (mascLive && now - blinkAt > bp) {            // sbatte le palpebre (solo chi e' ok)
      blinkAt = now; blinkClosed = !blinkClosed;
      for (int i = 0; i < g_mascN; i++) {
        if (g_masc[i].mood != 1) continue;
        for (int k = 0; k < 2; k++) {
          if (!g_masc[i].lid[k]) continue;
          if (blinkClosed) lv_obj_clear_flag(g_masc[i].lid[k], LV_OBJ_FLAG_HIDDEN);
          else             lv_obj_add_flag(g_masc[i].lid[k], LV_OBJ_FLAG_HIDDEN);
        }
      }
    }
    if (g_slideSec > 0 && g_ui.tv && !g_refreshing && !g_mo.scrim && !g_nt.scrim && !g_tmMenu && !g_wxWeek && g_screenMode < 2 &&
        now - g_lastTouchMs > 10000 && now - g_lastSlideMs > (uint32_t)g_slideSec * 1000) {
      g_lastSlideMs = now;
      int next = (g_curTile + 1) % NTILES;
      lv_tileview_set_tile_by_index(g_ui.tv, next, 0, LV_ANIM_ON);
    }

    // pausa a tempo scaduta: riprende da sola
    if (g_userPause && g_pauseUntil) {
      time_t tn = time(nullptr);
      if (tn > 1000000000L && (uint32_t)tn >= g_pauseUntil) pause_set(false, 0);
    }
    // torna alla home dopo N minuti senza tocchi (una volta per periodo di inattivita')
    static uint32_t homedFor = 0;
    if (g_clockIdx && g_ui.tv && g_curTile != 0 && !g_mo.scrim && !g_nt.scrim && !g_pauseMenu && !g_tmMenu && !g_wxWeek && g_screenMode < 2 &&
        homedFor != g_lastTouchMs && now - g_lastTouchMs > CLOCK_MIN[g_clockIdx] * 60000UL) {
      homedFor = g_lastTouchMs;
      lv_tileview_set_tile_by_index(g_ui.tv, 0, 0, LV_ANIM_ON);
    }

    // Momenti di soglia: mostra quello in sospeso e anima l'overlay attivo
    if (g_pendWin >= 0 && !g_mo.scrim && !g_refreshing && g_screenMode < 2) {
      show_moment(g_pendWin, g_pendThr);
      g_pendWin = -1;
    }
    if (g_mo.scrim) moment_tick();
    // Avvisi di Claude Code e del timer: uno nuovo riaccende lo schermo. Di notte (schermo spento o
    // orologio) quelli di Claude Code non compaiono; il timer invece si', l'hai chiesto tu.
    if (g_ntPend == NT_CLAUDE && g_screenMode >= 2 && !g_ntT0) g_ntPend = NT_NONE;
    if (g_ntPend && !g_mo.scrim && !g_refreshing) {
      int k = g_ntPend;
      g_ntPend = NT_NONE;
      if (!g_ntT0) g_lastTouchMs = millis();
      if (k == NT_CLAUDE) cc_show(); else tm_show();
    }
    if (g_nt.scrim) notice_tick();
  }

  delay(5);
}

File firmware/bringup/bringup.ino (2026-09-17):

/**
 * Gadget Valorant — Fase 1: BRING-UP (colori + touch)
 * Scheda: Guition JC4832W535 (ESP32-S3, AXS15231B QSPI), 480x320 orizzontale.
 *
 * Obiettivo: verificare sull'HARDWARE REALE che i colori escano corretti e che il tocco
 * abbia l'orientamento giusto, PRIMA di investire nella UI.
 *
 * Pipeline del display copiata dal riferimento funzionante (esp32_controller):
 *   Arduino_Canvas rotation=0  +  rotazione manuale 270° CW nel flush  +  gfx->flush()
 * Vedi firmware/RIFERIMENTO-HARDWARE-LVGL.md
 */
#include <Arduino.h>
#include <Arduino_GFX_Library.h>
#include <lvgl.h>
#include <Wire.h>
#include "config.h"
#include "touch.h"

Arduino_Canvas *gfx = nullptr;
static uint16_t *canvas_fb = nullptr;
AXS15231B_Touch touch_dev(TOUCH_SCL, TOUCH_SDA, TOUCH_INT, TOUCH_ADDR, 3); // 3 = USB a sinistra

static lv_obj_t *g_dot = nullptr;
static lv_obj_t *g_touch_lbl = nullptr;

// ---- Flush: LVGL 480x320 -> ruota di 270° CW -> Canvas 320x480 -> QSPI ----
static void disp_flush_cb(lv_display_t *disp, const lv_area_t *area, uint8_t *px_map) {
    uint16_t *src = (uint16_t *)px_map;
    for (int ly = 0; ly < SCREEN_HEIGHT; ly++) {
        uint16_t *src_row = src + ly * SCREEN_WIDTH;
        for (int lx = 0; lx < SCREEN_WIDTH; lx++) {
            canvas_fb[(479 - lx) * 320 + ly] = src_row[lx];
        }
    }
    gfx->flush();
    lv_disp_flush_ready(disp);
}

static void touch_read_cb(lv_indev_t *indev, lv_indev_data_t *data) {
    uint16_t x, y;
    if (touch_dev.touched()) {
        touch_dev.readData(&x, &y);
        data->point.x = x;
        data->point.y = y;
        data->state = LV_INDEV_STATE_PRESSED;
        if (g_dot) lv_obj_set_pos(g_dot, (int)x - 11, (int)y - 11);
        if (g_touch_lbl) lv_label_set_text_fmt(g_touch_lbl, "TOCCO: x=%d  y=%d", x, y);
        Serial.printf("touch: x=%d y=%d\n", x, y);
    } else {
        data->state = LV_INDEV_STATE_RELEASED;
    }
}

static void make_swatch(lv_obj_t *parent, uint32_t hex, const char *name, uint32_t textHex) {
    lv_obj_t *sw = lv_obj_create(parent);
    lv_obj_set_size(sw, 142, 62);
    lv_obj_set_style_bg_color(sw, lv_color_hex(hex), 0);
    lv_obj_set_style_bg_opa(sw, LV_OPA_COVER, 0);
    lv_obj_set_style_border_width(sw, 0, 0);
    lv_obj_set_style_radius(sw, 8, 0);
    lv_obj_set_style_pad_all(sw, 0, 0);
    lv_obj_t *l = lv_label_create(sw);
    lv_label_set_text(l, name);
    lv_obj_set_style_text_color(l, lv_color_hex(textHex), 0);
    lv_obj_set_style_text_font(l, &lv_font_montserrat_14, 0);
    lv_obj_center(l);
}

void setup() {
    Serial.begin(115200);
    delay(1200);
    Serial.println("\n=== Valorant Gadget — BRING-UP (colori + touch) ===");

    // --- Display (Canvas rotation=0 => colori corretti) ---
    Arduino_DataBus *bus = new Arduino_ESP32QSPI(
        TFT_CS, TFT_SCK, TFT_SDA0, TFT_SDA1, TFT_SDA2, TFT_SDA3);
    Arduino_GFX *g = new Arduino_AXS15231B(bus, GFX_NOT_DEFINED, 0, false, 320, 480);
    gfx = new Arduino_Canvas(320, 480, g, 0, 0, 0);
    if (!gfx->begin(QSPI_FREQ)) {
        Serial.println("FATAL: init del display fallito!");
        while (1) delay(1000);
    }
    gfx->fillScreen(0x0000);
    gfx->flush();
    canvas_fb = gfx->getFramebuffer();
    pinMode(TFT_BL, OUTPUT);
    digitalWrite(TFT_BL, HIGH);
    Serial.println("Display: OK");

    // --- Touch ---
    bool t_ok = touch_dev.begin();
    Serial.printf("Touch: %s\n", t_ok ? "OK" : "FALLITO (verificare I2C)");

    // --- LVGL ---
    lv_init();
    lv_tick_set_cb([]() -> uint32_t { return millis(); });

    uint32_t bufSize = SCREEN_WIDTH * SCREEN_HEIGHT * sizeof(lv_color_t);
    lv_color_t *buf = (lv_color_t *)heap_caps_malloc(bufSize, MALLOC_CAP_SPIRAM | MALLOC_CAP_8BIT);
    if (!buf) {
        Serial.println("FATAL: alloc PSRAM fallita (abilitare PSRAM=opi!)");
        while (1) delay(1000);
    }
    lv_display_t *disp = lv_display_create(SCREEN_WIDTH, SCREEN_HEIGHT);
    lv_display_set_flush_cb(disp, disp_flush_cb);
    lv_display_set_buffers(disp, buf, NULL, bufSize, LV_DISPLAY_RENDER_MODE_FULL);

    lv_indev_t *indev = lv_indev_create();
    lv_indev_set_type(indev, LV_INDEV_TYPE_POINTER);
    lv_indev_set_read_cb(indev, touch_read_cb);
    Serial.println("LVGL: OK");

    // --- UI di test ---
    lv_obj_t *scr = lv_screen_active();
    lv_obj_set_style_bg_color(scr, lv_color_hex(0x0b0b18), 0);
    lv_obj_set_style_bg_opa(scr, LV_OPA_COVER, 0);

    lv_obj_t *title = lv_label_create(scr);
    lv_label_set_text(title, "VALO GADGET  -  BRING-UP");
    lv_obj_set_style_text_color(title, lv_color_hex(0xFFFFFF), 0);
    lv_obj_set_style_text_font(title, &lv_font_montserrat_18, 0);
    lv_obj_align(title, LV_ALIGN_TOP_MID, 0, 10);

    lv_obj_t *sub = lv_label_create(scr);
    lv_label_set_text(sub, "Colori corretti? Tocca lo schermo (angolo sup. sin. = x,y bassi).");
    lv_obj_set_style_text_color(sub, lv_color_hex(0x94a3b8), 0);
    lv_obj_set_style_text_font(sub, &lv_font_montserrat_12, 0);
    lv_obj_align(sub, LV_ALIGN_TOP_MID, 0, 36);

    // Griglia di colori (3 per riga, con wrap)
    lv_obj_t *grid = lv_obj_create(scr);
    lv_obj_set_size(grid, 462, 150);
    lv_obj_align(grid, LV_ALIGN_CENTER, 0, 0);
    lv_obj_set_style_bg_opa(grid, LV_OPA_TRANSP, 0);
    lv_obj_set_style_border_width(grid, 0, 0);
    lv_obj_set_style_pad_all(grid, 4, 0);
    lv_obj_set_flex_flow(grid, LV_FLEX_FLOW_ROW_WRAP);
    lv_obj_set_flex_align(grid, LV_FLEX_ALIGN_SPACE_BETWEEN, LV_FLEX_ALIGN_CENTER, LV_FLEX_ALIGN_CENTER);
    lv_obj_clear_flag(grid, LV_OBJ_FLAG_SCROLLABLE);

    make_swatch(grid, 0xFF0000, "ROSSO", 0xFFFFFF);
    make_swatch(grid, 0x00FF00, "VERDE", 0x000000);
    make_swatch(grid, 0x0000FF, "BLU", 0xFFFFFF);
    make_swatch(grid, 0x7C3AED, "VIOLA", 0xFFFFFF); // brand
    make_swatch(grid, 0xF43F5E, "ROSA/CTA", 0xFFFFFF); // brand
    make_swatch(grid, 0xFFFFFF, "BIANCO", 0x000000);

    // Label del tocco
    g_touch_lbl = lv_label_create(scr);
    lv_label_set_text(g_touch_lbl, "TOCCO: in attesa...");
    lv_obj_set_style_text_color(g_touch_lbl, lv_color_hex(0xa78bfa), 0);
    lv_obj_align(g_touch_lbl, LV_ALIGN_BOTTOM_MID, 0, -12);

    // Punto che segue il dito
    g_dot = lv_obj_create(scr);
    lv_obj_set_size(g_dot, 22, 22);
    lv_obj_set_style_radius(g_dot, LV_RADIUS_CIRCLE, 0);
    lv_obj_set_style_bg_color(g_dot, lv_color_hex(0xF43F5E), 0);
    lv_obj_set_style_border_width(g_dot, 2, 0);
    lv_obj_set_style_border_color(g_dot, lv_color_hex(0xFFFFFF), 0);
    lv_obj_set_pos(g_dot, 229, 149);

    Serial.println("=== Bring-up pronto. Guarda lo schermo. ===");
}

void loop() {
    lv_task_handler();
    delay(5);
}

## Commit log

2026-09-17 Ritmo Code v3.6
    I limiti d'uso di Claude Code in tempo reale su un ESP32-S3 con schermo touch 3,5":
    firmware, pannello web, simulatore e app Windows "Ritmo Code PC Monitor".
    Sviluppato da Luca Marullo - Innova Design Studio, a partire da claude-usage-stick
    di Benevid Felix (crediti completi nel README).
    Claude-Session: https://claude.ai/code/session_01HinFd4zDwdduYokituREmD
    [Case_JC3248W535C.stl, ClowDeck-Base.stl, ClowDeck-Case-Display-Holder.stl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]
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2026-09-18 Avvisi di Claude Code: Clawd avvisa quando Claude ha finito o aspetta un permesso
    - PC Monitor 1.2.0: riceve gli hook UserPromptSubmit/Stop/Notification su
    127.0.0.1:8765/claude/*, inoltra subito l'evento al dispositivo (POST /claude)
    e lo espone in data.json; installa/rimuove gli hook in ~/.claude/settings.json
    dalla pagina di stato senza toccare il resto del file.
    - Firmware: avviso a schermo intero con durata del lavoro, resta finche' non
    lo tocchi o scrivi di nuovo a Claude (max 30 min), sopravvive ai rebuild;
    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
2026-09-18 Timer e pomodoro, firmware 3.7
    - Tocca l'ora nella home: pomodoro 25/5 (pausa lunga di 15 min dopo il
    quarto, poi si ferma) o timer da 5, 10, 15, 30 min; se e' in corso il menu
    offre ferma, salta fase o +5 min.
    - Conto alla rovescia in testata, fase e ora di fine al posto della data,
    pomodori di oggi contati (NVS).
    - A fine fase Clawd a schermo intero: l'avviso di Claude Code diventa un
    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
2026-09-18 Pomodoro: icona in home, conto alla rovescia sotto l'ora, tre impostazioni pronte
    - Pomodoro disegnato accanto alla riga sotto l'ora: la riga apre il menu
    come l'ora e, con il timer in corso, mostra il conto alla rovescia e la fine.
    - Menu: prima tre impostazioni del pomodoro (25/5, 50/10, 15/3 con pausa
    lunga 15/20/10), poi i timer da 5, 10, 15, 30 min.
    Claude-Session: https://claude.ai/code/session_01JaARnFnnywFHSLEuyBzDyP
2026-09-18 Home: meno spazio sotto la riga del pomodoro, metro di claude piu' arioso
    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
2026-09-18 Home: riquadro claude centrato tra la riga del pomodoro e il riquadro pc
    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
2026-09-18 Home: riga della data centrata tra l'ora e il riquadro claude
    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
2026-09-19 Home: riquadro claude centrato tra la data e il riquadro pc (17 px sopra e sotto)
    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
2026-09-19 Display: sequenza di inizializzazione del pannello 320x480 (JC3248W535)
    Senza, Arduino_GFX usava quella del pannello 180x640: con tensioni e VCOM
    sbagliate l'immagine dopo un po' sbiadiva lasciando i numeri in trasparenza.
    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
2026-09-19 Meteo: tocca il meteo nella home per le previsioni dei 7 giorni
    Open-Meteo con forecast_days=7 e probabilita' massima di pioggia per giorno;
    jarr non sconfina piu' nell'array successivo.
    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
2026-09-19 Firmware: cartella e sketch rinominati in ritmo_code
    Il file da caricare diventa ritmo_code.ino.bin; la pagina /update cita anche
    il nome del file della release. Aggiornati script, README e simulatore.
    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
    [partitions.csv]
2026-09-19 Suoni e notifiche sul PC per gli avvisi del dispositivo
    - Firmware: quando compare un avviso (timer, pomodoro, Claude Code, soglie,
    reset) lo manda al PC collegato (POST /notify); di notte niente.
    Impostazioni -> suoni sul pc.
    - PC Monitor 1.3.0: suono diverso per evento (generato al volo, solo libreria
    standard) e notifica di Windows dall'icona; accetta solo il dispositivo
    collegato. Suono, notifica e volume nella pagina di stato, con Prova.
    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
    [extras.cpp]
2026-09-19 PC Monitor: suoni di Windows (MessageBeep) come predefiniti
    Nelle sessioni di desktop remoto PlaySound restava muto, MessageBeep no.
    Le melodie Ritmo Code restano come opzione nella pagina di stato.
    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
2026-09-19 Home: tocca il riquadro claude per la pagina ora, il riquadro pc per la pagina pc
    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
2026-09-19 3.9.1: l'avviso di Claude si chiude da solo (5 s, 10 s, 30 s o mai)
    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
2026-09-19 3.9.2: Claude al lavoro in testata e in home, tasto aggiorna nel meteo della settimana
    - La ✻ della testata gira come lo spinner di Claude Code mentre una sessione
    lavora; il riquadro claude in home dice quante sono al lavoro.
    - PC Monitor 1.3.1: manda il numero di sessioni al lavoro con ogni evento e
    non ne conta mai piu' di quelle aperte (Esc a meta' lascia una sessione
    senza Stop).
    - Riquadro della settimana: tasto aggiorna e ora dell'ultimo aggiornamento.
    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
2026-09-19 3.9.2: aggiornamento del firmware con un tocco dalle release di GitHub
    - Controllo dell'ultima release (api.github.com) dopo l'avvio e una volta al
    giorno; la testata mostra 'nuova v...'. Impostazioni -> sistema ->
    aggiornamenti: cerca / installa, con percentuale e barra; se fallisce il
    firmware attuale resta.
    - Installazione nel task di rete (stack in RAM interna: la flash non si
    scrive da uno stack in PSRAM), download con i redirect di GitHub.
    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
2026-09-19 3.9.3: controllo aggiornamenti senza riavvio, versione nella schermata di avvio
    Il controllo leggeva l'API JSON di GitHub con getString(), che aspetta i dati
    senza cedere il core: con la risposta lunga il watchdog riavviava il
    dispositivo. Ora basta il reindirizzamento di releases/latest (tag) e
    l'indirizzo del .bin si ricava dal nome; il download cede il core a ogni blocco.
    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
2026-09-20 3.9.9: il controllo aggiornamenti riprova una volta prima di dare errore
    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
    [config.h]
2026-09-20 3.9.9: prossimo evento in home e nel tray, timer che sopravvive al riavvio, titoli piu' lunghi
    - calendario: titoli fino a 60 caratteri (prima 44 sul PC, 45 sul dispositivo)
    - viste giorno/settimana/mese: nota "fuori dal periodo scaricato" quando si naviga oltre i dati
    - home: la riga sotto l'ora mostra anche gli eventi oltre l'ora ("oggi 15:00: ...")
    - home: in pausa resta solo la parola gialla, non si tocca piu' con "reset tra ..."
    - timer e pomodoro salvati in NVS: dopo un riavvio riprendono da dove erano
    - schermo: l'ora si sposta di due pixel ogni dieci minuti e ogni mezz'ora si ridisegna tutto
    - PC Monitor 1.6.0: suggerimento del tray con il prossimo evento e accenti corretti
    Co-Autho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
2026-09-21 3.9.9: dopo un PIN sbagliato si attendono 15 secondi fissi
    Prima l'attesa partiva da 60 s e raddoppiava a ogni errore. Il limite vero
    resta quello dei 10 tentativi, dopo i quali le credenziali vengono cancellate.
    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
    [config.h]
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2026-09-22 3.9.11: niente piu' riavvii dal task watchdog quando l'API risponde lenta
    Il core dump del riavvio: task watchdog su IDLE0, con il task "net" dentro
    HTTPClient::POST -> handleHeaderResponse -> Stream::timedRead, che aspetta le
    intestazioni di Anthropic girando a vuoto (timeout API 15 s, watchdog 5 s).
    I task di rete ("net" ed "extra") ora girano a priorita' 0 come IDLE0 e si
    alternano a ogni tick. In piu': motivo dell'ultimo riavvio sulla seriale e in
    /api/status ("reset", "uptime").
    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
2026-09-22 3.9.11: conto alla rovescia in home
    Con un conto attivo (il piu' vicino nel futuro, o quello arrivato oggi) il
    riquadro claude e' largo 314 come il pc, senza reset/stato/modelli e con barre
    da 18 blocchi; a destra, sopra pomodoro/timer/calendario, un riquadro da 132
    con il titolo nella legenda e il numero grande (gg, ore, min, "ci siamo!").
    Tocca per aprire il conto. La home si ricostruisce da sola quando un conto si
    accende o si spegne, appena non ci sono finestre aperte.
    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
2026-09-27 3.9.12 + PC Monitor 1.9.0: sonda modelli, previsioni, progetti, pagina sessioni
    Firmware 3.9.12
    - sonda modelli: prompt di sistema di Claude Code e User-Agent 2.1.281 (niente piu' 429 finti
    su Sonnet/Opus/Fable), error.message salvato nei risultati; Opus predefinito claude-opus-5-5
    - certificati: aggiunte GTS Root R1/R4 (api.anthropic.com falliva a volte con X509)
    - diagnostica di rete in /api/status: heap, fails, err, err_at
    - previsione della 5h nella pagina ora e in home ("finisce 16:40")
    - avviso settimana sopra 70/85/95% se la quota finisce almeno 12 h prima del reset
    - progetti di Claude Code nella pagina ritmo, con pannello completo al tocco
    - pagina sessioni: 3x2 riquadri con stato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
    [api.cpp, config.h, extras.cpp]
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
